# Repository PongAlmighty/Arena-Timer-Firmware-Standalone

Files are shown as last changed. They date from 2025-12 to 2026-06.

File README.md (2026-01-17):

# Arena Timer Firmware

A professional countdown timer system for competitive arenas, combat sports, and event timing. Built on the Waveshare RP2040-Zero with a vibrant 64x32 RGB LED matrix display, web-based control, and seamless integration with [FightTimer](https://github.com/PongAlmighty/FightTimer) by PongAlmighty.

## Features

### Display & Visual Customization
- **64x32 RGB LED Matrix** with full color control
- **Dynamic Color Thresholds** - automatically change colors as time decreases
- **Multiple Font Choices** - Sans, Serif, Monospace, Retro/Pixel styles
- **Adjustable Brightness** - 0-255 levels for any lighting condition
- **Character Spacing Control** - fine-tune text appearance
- **Display Rotation** - flip orientation 180° with one button

### Timer Controls
- **Countdown Mode** - configurable duration up to 60 minutes
- **Start/Pause/Reset** - full manual control
- **Sub-Second Precision** - displays tenths of seconds under 1 minute
- **Visual States** - blinking when paused, flashing when expired

### Web Interface
- **Responsive Three-Column Layout** - Timer controls, color settings, system status
- **Real-Time Console** - live event logging with timestamps
- **Live Updates** - automatic status refresh and button state management
- **Mobile Friendly** - works on phones, tablets, and desktops

### Network & Integration
- **DHCP Support** with static IP fallback (10.0.0.21)
- **mDNS Hostname** - access via `http://arenatimer.local`
- **FightTimer Integration** - Socket.IO connection for synchronized timing (credit: [PongAlmighty](https://github.com/PongAlmighty/))
- **RESTful API** - control timer programmatically

## Hardware

### Required Components
- **Silicognition RP2040-Shim** microcontroller
  - Designed to solder directly to the HUB75 input header on the back of the matrix
  - Provides integrated power regulation (5V to 3.3V)
- **64x32 RGB LED Matrix Panel** (HUB75 interface, P5 pitch recommended)
- **W5500 Ethernet Module** (SPI interface, PoE-FeatherWing or compatible)
- **5V Power Supply** (minimum 2A, 4A recommended for full brightness / more pixels)
  - I used a 5V 20W PoE splitter mounted to the back of the enclosure

### Pin Configuration

**Important:** This firmware uses a specific pin mapping optimized for the RP2040-Shim mounting directly to the HUB75 header. The Ethernet module uses SPI1 to avoid conflicts with the Matrix control signals.

#### RP2040-Shim GPIO Pinout

| RP2040 GPIO | Function | Peripheral | Shim Label | Notes |
|---|---|---|---|---|
| **GPIO 0** | Output Enable (OE) | Matrix | TX | Active low |
| **GPIO 1** | Latch (LAT) | Matrix | RX | |
| **GPIO 6** | Red Data 2 (R2) | Matrix | D4 | Bottom half |
| **GPIO 10** | SPI Clock | Ethernet | SCK | SPI1 |
| **GPIO 11** | SPI MOSI | Ethernet | MOSI | SPI1 |
| **GPIO 12** | SPI MISO | Ethernet | MISO | SPI1 |
| **GPIO 16** | Red Data 1 (R1) | Matrix | SDA | Top half |
| **GPIO 17** | Green Data 1 (G1) | Matrix | SCL | Top half |
| **GPIO 19** | Green Data 2 (G2) | Matrix | D6 | Bottom half |
| **GPIO 20** | Blue Data 1 (B1) | Matrix | D9 | Top half |
| **GPIO 21** | SPI Chip Select | Ethernet | D11 | CS for W5500 |
| **GPIO 22** | Matrix Clock (CLK) | Matrix | D13 | Pixel clock |
| **GPIO 25** | Blue Data 2 (B2) | Matrix | D25 | Bottom half |
| **GPIO 26** | Address D | Matrix | A3 | Row select |
| **GPIO 27** | Address C | Matrix | A2 | Row select |
| **GPIO 28** | Address B | Matrix | A1 | Row select |
| **GPIO 29** | Address A | Matrix | A0 | Row select |

> **Warning:** GPIO 24 is hardwired to VBUS sensing. Never use for I/O or the board will crash.

#### HUB75 Connector Pinout (Matrix Side)

| HUB75 Pin | Signal | RP2040 GPIO | Function |
|---|---|---|---|
| 1 | R1 | GPIO 16 | Red Data (Top) |
| 2 | G1 | GPIO 17 | Green Data (Top) |
| 3 | B1 | GPIO 20 | Blue Data (Top) |
| 4 | GND | - | Ground |
| 5 | R2 | GPIO 6 | Red Data (Bottom) |
| 6 | G2 | GPIO 19 | Green Data (Bottom) |
| 7 | B2 | GPIO 25 | Blue Data (Bottom) |
| 8 | GND | - | Ground |
| 9 | A | GPIO 29 | Address A |
| 10 | B | GPIO 28 | Address B |
| 11 | C | GPIO 27 | Address C |
| 12 | D | GPIO 26 | Address D |
| 13 | CLK | GPIO 22 | Pixel Clock |
| 14 | LAT | GPIO 1 | Latch |
| 15 | OE | GPIO 0 | Output Enable |
| 16 | GND | - | Ground |

> **Note:** The RP2040-Shim is powered by connecting 5V from the matrix power supply to the VUSB pin (3rd pin on right header). The onboard regulator converts this to 3.3V for logic. Do not connect USB while external 5V is applied unless using a data-only cable.

For complete wiring diagrams and PCB design files, see [wiring_connections.md](wiring_connections.md).

### Custom PCB & 3D Enclosure

**Custom PCB** is currently in production and will be added to this repository once tested and verified.

**3D Enclosure** files for a custom LED matrix enclosure are available in the `3d-models/` directory:
- `Timer Assembly v23.step` - STEP format for CAD editing
- `Timer Assembly v23.f3z` - Fusion 360 archive format

Files are print-ready and designed for:
- Standard 64x32 P5 RGB matrix panels
- RP2040-Shim direct mounting to HUB75 header
- PoE splitter bracket mount

## Quick Start

### 1. Flash Firmware
```bash
pio run --target upload
```

### 2. Network Connection
The timer will attempt DHCP, then fall back to `10.0.0.21` if unavailable. The assigned IP displays on the matrix for 5 seconds at startup.

### 3. Web Interface
Access the control panel at:
- `http://arenatimer.local` (mDNS)
- `http://[IP_ADDRESS]` (direct)

Use the web interface to:
- Start, pause, and reset the timer
- Set duration (minutes and seconds)
- Configure color thresholds for time-based alerts
- Adjust display settings (font, brightness, letter spacing)
- Flip display orientation
- Monitor system status and event logs

### 4. FightTimer Integration
To connect with FightTimer:
1. Ensure FightTimer is running on your network
2. In the **WebSocket Connection** section, enter:
   - **Host**: IP address of the computer running FightTimer
   - **Port**: `8765` (default Socket.IO port)
   - **Path**: `/socket.io/`
3. Click **Connect**

The timer will automatically sync with FightTimer's start/stop/reset commands and duration settings.

**What Gets Synchronized:**
- ✅ Timer start/stop/reset commands
- ✅ Duration changes
- ✅ Time remaining updates
- ✅ Expired/paused states

FightTimer sends `timer_update` events via Socket.IO that control the Arena Timer display.

**Alternative connection methods:**

Via code in `src/main.cpp`:
```cpp
void setup() {
    // ... existing setup code ...
    wsClient->connect("192.168.1.100", 8765, "/socket.io/");
}
```

Via API endpoint:
```bash
curl -X POST "http://arenatimer.local/api/websocket/connect" \
  -d "host=192.168.1.100&port=8765&path=/socket.io/"
```

## Configuration

### Network Settings
Edit `src/main.cpp` to change network defaults:
```cpp
uint8_t mac[] = {0xDE, 0xAD, 0xBE, 0xEF, 0xFE, 0xED};  // MAC address
uint8_t static_ip[] = {10, 0, 0, 21};                   // Static IP fallback
const char* hostname = "arenatimer";                     // mDNS hostname
```

### Display Settings
Configure default display settings in `src/main.cpp`:
```cpp
// Set default font
timerDisplay.setFont(&FreeSansBold12pt7b);

// Set default duration (hours, minutes, seconds)
timerDisplay.getTimer().setDuration({0, 3, 0});  // 3 minutes

// Color thresholds (set via web interface or programmatically)
timerDisplay.addColorThreshold(120, 255, 255, 0);  // Yellow at 2 minutes
timerDisplay.addColorThreshold(60, 255, 0, 0);     // Red at 1 minute
```

### Available Fonts
- **Sans**: `FreeSans9pt7b`, `FreeSans12pt7b`, `FreeSansBold9pt7b`, `FreeSansBold12pt7b`
- **Serif**: `FreeSerif9pt7b`, `FreeSerif12pt7b`, `FreeSerifBold9pt7b`, `FreeSerifBold12pt7b`
- **Mono**: `FreeMono9pt7b`, `FreeMono12pt7b`, `FreeMonoBold9pt7b`, `FreeMonoBold12pt7b`
- **Retro**: `Org_01`, `Picopixel`, `TomThumb` (ultra-compact pixel fonts)
- **Custom**: `Aquire_BW0ox12pt7b`, `AquireBold_8Ma6012pt7b`, `AquireLight_YzE0o12pt7b`

### Pin Configuration
Default pins are defined in `include/RGBMatrix.h` for the Waveshare RP2040-Zero. Modify if using different pin connections.

### Performance Optimization
The firmware includes debug flags that can be disabled for optimal timing performance:

```cpp
// src/main.cpp
#define DEBUG_MAIN false

// src/WebServer.cpp
#define DEBUG_WEBSERVER false

// src/WebSocketClient.cpp
#define DEBUG_WEBSOCKET false
```

When all debug flags are `false`, Serial output is disabled, eliminating timing delays. This is recommended for production use.

## API Reference

The timer exposes a RESTful API for programmatic control:

### Timer Control
```bash
# Start timer
POST /api?action=start

# Pause timer
POST /api?action=pause

# Reset timer
POST /api?action=reset

# Flip display orientation
POST /api?action=flip
```

### Settings
```bash
# Update timer settings
POST /api?action=settings&duration=180&font=4&spacing=3&brightness=255

# Update color thresholds
POST /api/thresholds
Content-Type: application/x-www-form-urlencoded
thresholds=120:%23FFFF00|60:%23FF0000&default=%2300FF00
```

### Status Information
```bash
# Get timer status
GET /api/status

# Get network information
GET /api/network/status

# Get WebSocket connection status
GET /api/websocket/status
```

### WebSocket Connection
```bash
# Connect to FightTimer
POST /api/websocket/connect
Content-Type: application/x-www-form-urlencoded
host=192.168.1.100&port=8765&path=/socket.io/

# Disconnect
POST /api/websocket/disconnect
```

## Troubleshooting

### Display Issues
- **Blank display**: Check power supply (5V, minimum 2A recommended)
- **Corrupted display**: Verify HUB75 cable connections
- **Wrong colors**: Check RGB pin mappings in `src/RGBMatrix.cpp`

### Network Issues
- **Can't access web interface**: Check Ethernet cable, verify IP on display at startup
- **DHCP not working**: Timer falls back to static IP `10.0.0.21`
- **mDNS not resolving**: Try direct IP address instead

### FightTimer Connection
- **Won't connect**: Verify FightTimer is running and accessible at the specified host/port
- **Connects but no updates**: Check that FightTimer is sending `timer_update` Socket.IO events
- **Frequent disconnects**: Check network stability between devices

## Development

### Build Environment
- **Framework**: Arduino
- **Platform**: Raspberry Pi Pico (RP2040)
- **Tool**: PlatformIO

### Key Libraries
- **Adafruit Protomatter** - RGB matrix driver
- **Ethernet** - W5500 network interface
- **WebSockets** - Socket.IO client (links2004/arduinoWebSockets)
- **EthernetBonjour** - mDNS support

### Building from Source
```bash
# Clone repository
git clone https://github.com/EVAC-AZ/Arena-Timer-Firmware.git
cd Arena-Timer-Firmware

# Install dependencies
pio pkg install

# Build and upload
pio run --target upload

# Monitor serial output (optional)
pio device monitor
```

### Project Structure
```
arena-timer-firmware/
├── src/
│   ├── main.cpp              # Entry point and configuration
│   ├── Timer.cpp             # Core timer logic
│   ├── TimerDisplay.cpp      # LED matrix display control
│   ├── RGBMatrix.cpp         # Low-level matrix driver
│   ├── WebServer.cpp         # Web server and API
│   └── WebSocketClient.cpp   # Socket.IO client
├── include/
│   ├── Timer.h
│   ├── TimerDisplay.h
│   ├── RGBMatrix.h
│   ├── WebServer.h
│   ├── WebSocketClient.h
│   └── CustomFonts/          # Custom font definitions
├── 3d-models/                # Enclosure models
├── docs/                     # Documentation
├── platformio.ini            # Build configuration
└── README.md
```

### Future Plans
A standalone Arduino/PlatformIO library is planned to simplify integration of this timer system into other projects. The goal is to separate the timing/web UI/FightTimer integration code from the hardware-specific code, allowing use with different display hardware and microcontrollers (ESP32, ESP8266, etc.).

## Credits

- **FightTimer Integration**: [PongAlmighty/FightTimer](https://github.com/PongAlmighty/FightTimer) - Synchronized timing system for combat sports
- **RGB Matrix Control**: Adafruit Protomatter library
- **WebSocket Library**: Arduino WebSockets by links2004
- **Enclosure Design**: EVAC-AZ

## License

This project is open source. See `LICENSE` for details.

## Contributing

Contributions are welcome! Please:
1. Fork the repository
2. Create a feature branch
3. Make your changes with clear commits
4. Submit a pull request

For bug reports and feature requests, open an issue on GitHub.

---

**Built for arena timing excellence** 🏆

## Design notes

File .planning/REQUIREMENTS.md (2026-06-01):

# Requirements — Arena Timer Local Control & Sync

## v1 Requirements

### Button Hardware

- [x] **BTN-01**: GPIO14 and GPIO15 initialized as `INPUT_PULLUP` (active-low) in `setup()` — eliminates floating-pin phantom presses at boot
- [x] **BTN-02**: Button states polled via Bounce2 library; poll is the first call in `loop()` to prevent starvation during HTTP blocking
- [x] **BTN-03**: `thomasfredericks/Bounce2@^2.71` added to `platformio.ini` `lib_deps`; debounce interval set to 25ms

### Button UX

- [x] **BTN-04**: Button 1 (GPIO14) solo press toggles between running and stopped only: RESET → RUNNING on first press; RUNNING → STOPPED on press; STOPPED → RUNNING on press. Button 1 alone NEVER resets the timer — reset is only possible via the chord (BTN-06).
- [x] **BTN-05**: Button 2 (GPIO15) held for ≥400ms enters "armed" state; releasing Button 2 at any point disarms with no further action taken
- [x] **BTN-06**: Button 1 pressed while system is in armed state → stop & reset (timer returns to RESET state regardless of whether it was RUNNING or STOPPED)
- [x] **BTN-07**: While armed, display overrides to yellow "STOP?" text blinking at 1 Hz; display returns to normal timer on disarm or confirm

### FightTimer Integration

- [x] **SYNC-01**: Every button action (start, stop, reset) emits a `timer_control` Socket.IO event to FightTimer with the corresponding action string before (not after) local timer state change
- [x] **SYNC-02**: `handleTimerUpdate()` suppresses incoming `timer_update` for 500ms after any local button emit, matched by action type; suppression is one-shot (consumed on first match)
- [x] **SYNC-03**: On receiving `timer_update {action: start}`, Arena Timer sets its timer to FightTimer's actual remaining time — if `time_left` is present in the event payload use it directly; otherwise emit `request_timer_status` and apply the response

## v2 Requirements (Deferred)

- Long-press Button 1 to cycle through fight duration presets (e.g., 2 min / 3 min / 5 min) — useful if FightTimer is unavailable
- Display of current timer duration on boot/reset for operator confirmation
- Configurable debounce threshold via web UI (for different button hardware on future PCB revisions)

## Out of Scope

- Pause as a distinct state — FightTimer has no pause action; stop-without-reset is the equivalent; the firmware stop/resume behavior maps to FightTimer start/stop
- Button interrupt mode — RP2040 hardware interrupts during WebSocket DMA transfers introduce race conditions with no debugging path; polling is correct for this architecture
- Authentication/authorization on button actions — device is on an isolated arena LAN; unauthenticated control is consistent with the existing web API
- Display orientation flip implementation — separate concern tracked in CONCERNS.md; not related to button control

## Traceability

| REQ-ID | Phase | Status |
|---|---|---|
| BTN-01 | Phase 1 | Complete |
| BTN-02 | Phase 1 | Complete |
| BTN-03 | Phase 1 | Complete |
| BTN-04 | Phase 2 | Complete |
| BTN-05 | Phase 2 | Complete |
| BTN-06 | Phase 2 | Complete |
| BTN-07 | Phase 2 | Complete |
| SYNC-01 | Phase 3 | Complete |
| SYNC-02 | Phase 3 | Complete |
| SYNC-03 | Phase 3 | Complete |

---
*Requirements defined: 2026-05-30*
*Traceability updated: 2026-05-31*

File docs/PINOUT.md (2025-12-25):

# Hardware Pinout (VERIFIED WORKING)

**Device**: Arena Timer  
**Controller**: Silicognition RP2040-Shim  
**Network**: POE-FeatherWing (W5500)  
**Display**: HUB75 RGB LED Matrix (64x32)

## Matrix Pin Mapping
| Signal | GPIO | Board Label |
|---|---|---|
| R1 | 16 | SDA |
| G1 | 17 | SCL |
| B1 | 20 | D9 |
| R2 | 6  | D4 |
| G2 | 19 | D6 |
| B2 | 25 | D25 |
| CLK | 22 | D13 |
| **LAT** | **1** | **RX** |
| **OE** | **0** | **TX** |
| A | 29 | A0 |
| B | 28 | A1 |
| C | 27 | A2 |
| D | 26 | A3 |

> **Note**: LAT and OE use GPIO 0/1 (TX/RX pins). USB Serial still works.

## Ethernet (SPI1)
| Signal | GPIO | Board Label |
|---|---|---|
| SCK | 10 | SCK |
| MOSI | 11 | MOSI |
| MISO | 12 | MISO |
| CS | 21 | D10 |

## ⚠️ Reserved Pins
- **GPIO 21**: Ethernet CS - do not use for matrix
- **GPIO 24**: VBUS sensing - never use as output (will crash!)
- **GPIO 23**: Internal Neopixel

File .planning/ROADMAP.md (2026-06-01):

# Roadmap: Arena Timer Firmware — Local Control & Sync

## Overview

Three horizontal layers build the complete button-control and sync capability. Phase 1 establishes the hardware foundation — stable GPIO init and a debounced ButtonHandler class. Phase 2 adds the full button UX on top of that stable base — start/stop toggle, chord-armed state, and the "STOP?" matrix overlay. Phase 3 closes the loop with FightTimer — outbound emit, echo suppression, and the startup sync fix that eliminates the ~1s display offset.

## Phases

**Phase Numbering:**

- Integer phases (1, 2, 3): Planned milestone work
- Decimal phases (2.1, 2.2): Urgent insertions (marked with INSERTED)

Decimal phases appear between their surrounding integers in numeric order.

- [x] **Phase 1: ButtonHandler Foundation** - GPIO init, Bounce2 integration, ButtonHandler class scaffold (completed 2026-05-31)
- [x] **Phase 2: Button UX** - Start/stop toggle, chord gesture, armed display overlay (completed 2026-05-31)
- [x] **Phase 3: Socket.IO Integration** - emitTimerControl(), echo suppression, timer sync fix

## Phase Details

### Phase 1: ButtonHandler Foundation

**Goal**: A stable, debounced button hardware layer exists and can be extended with behavior
**Depends on**: Nothing (first phase)
**Requirements**: BTN-01, BTN-02, BTN-03
**Success Criteria** (what must be TRUE):

  1. GPIO14 and GPIO15 are initialized as INPUT_PULLUP — pressing either button while monitoring serial shows a clean LOW transition with no phantom events at boot
  2. Bounce2 polls both buttons as the first call in loop(); a rapid sequence of button presses produces exactly one falling-edge event per physical press (no chatter)
  3. Bounce2 library is declared in platformio.ini lib_deps and the project builds without error

**Plans**: 2 plans
Plans:
**Wave 1**

- [x] 01-01-PLAN.md — Bounce2 lib_deps + ButtonHandler class scaffold (header + implementation)

**Wave 2** *(blocked on Wave 1 completion)*

- [x] 01-02-PLAN.md — Wire ButtonHandler into main.cpp + pio run build verification

### Phase 2: Button UX

**Goal**: A box ref can start, stop, and arm-then-reset the timer using the two physical buttons
**Depends on**: Phase 1
**Requirements**: BTN-04, BTN-05, BTN-06, BTN-07
**Success Criteria** (what must be TRUE):

  1. Pressing Button 1 alone toggles between running and stopped only: first press starts a RESET timer (→ RUNNING), second press stops the clock without resetting it (→ STOPPED), third press resumes (→ RUNNING). Button 1 alone never causes a reset under any circumstance — RESET state is only reachable via the chord (BTN-06)
  2. Holding Button 2 for ≥400ms shows yellow blinking "STOP?" on the matrix; releasing Button 2 without pressing Button 1 returns the display to normal with no timer state change
  3. While Button 2 is held (armed), pressing Button 1 stops and resets the timer regardless of whether it was running or stopped — matrix returns to RESET display

**Plans**: 2 plans
Plans:
**Wave 1**

- [x] 02-01-PLAN.md — ButtonHandler state machine (armed/disarmed, one-shot events) + WebSocketClient emitTimerControl stub

**Wave 2** *(blocked on Wave 1 completion)*

- [x] 02-02-PLAN.md — TimerDisplay armed overlay (yellow STOP? blink) + main.cpp button event routing

### Phase 3: Socket.IO Integration

**Goal**: All button actions sync to FightTimer bidirectionally with no echo loops and no startup time offset
**Depends on**: Phase 2
**Requirements**: SYNC-01, SYNC-02, SYNC-03
**Success Criteria** (what must be TRUE):

  1. Pressing any button emits a timer_control Socket.IO event (action: start / stop / reset) to FightTimer before the local timer state changes — FightTimer's log shows the event arriving within one LAN RTT
  2. After a local button emit, the echoed timer_update from FightTimer does not re-trigger the local timer; the suppression window is consumed on first match and does not block a subsequent legitimate remote action
  3. When FightTimer sends timer_update {action: start}, the Arena Timer's displayed countdown matches FightTimer's actual remaining time within one LAN RTT — the ~1s startup offset is eliminated

**Plans**: 1 plan
Plans:
**Wave 1**

- [x] 03-01-PLAN.md — WebSocketClient.h private members + WebSocketClient.cpp SYNC-01/02/03 implementation

## Progress

**Execution Order:**
Phases execute in numeric order: 1 → 2 → 3

| Phase | Plans Complete | Status | Completed |
|---|---|---|---|
| 1. ButtonHandler Foundation | 2/2 | Complete | 2026-05-31 |
| 2. Button UX | 2/2 | Complete | 2026-05-31 |
| 3. Socket.IO Integration | 1/1 | Complete | 2026-05-31 |

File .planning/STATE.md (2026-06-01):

---
gsd_state_version: 1.0
milestone: v1.0
milestone_name: milestone
status: complete
last_updated: "2026-05-31T00:00:00Z"
last_activity: 2026-05-31 -- All phases UAT complete; namespace emit fix, font restore fix, sync round-trip removed
progress:
  total_phases: 3
  completed_phases: 3
  total_plans: 5
  completed_plans: 5
  percent: 100
---

# Project State

## Project Reference

See: .planning/PROJECT.md (updated 2026-05-30)

**Core value:** A box ref can start, stop, and reset their fight clock with physical buttons, and those actions are immediately reflected in FightTimer — so cutting to that fight on screen always shows the correct, live time.
**Current focus:** All 3 phases complete — milestone v1.0 UAT done

## Current Position

All 3 phases complete. UAT done.

- Phase 01 (buttonhandler-foundation) — COMPLETE, UAT done
- Phase 02 (button-ux) — COMPLETE, UAT done
- Phase 03 (socket-io-integration) — COMPLETE, UAT done

Progress: [##########] 100%

## Performance Metrics

**Velocity:**

- Total plans completed: 5
- Average duration: —
- Total execution time: —

**By Phase:**

| Phase | Plans | Total | Avg/Plan |
|---|---|---|---|
| 01 | 2 | - | - |
| 02 | 2 | - | - |
| 03 | 1 | - | - |

**Recent Trend:**

- Last 5 plans: —
- Trend: —

*Updated after each plan completion*

## Accumulated Context

### Decisions

Decisions are logged in PROJECT.md Key Decisions table.
Recent decisions affecting current work:

- Architecture: ButtonHandler never calls _timer directly — all actions go through wsClient->emitTimerControl(), timer state changes flow through handleTimerUpdate() exclusively
- UX: Chord gesture (Button 2 held ≥400ms, then Button 1) for stop-reset — prevents accidental destructive action
- Echo suppression: 500ms per-action window, one-shot consumption — prevents FightTimer echo loop without blocking legitimate remote events
- request_timer_status payload must include {timer_id:1} — empty payload causes FightTimer to return timers_status (plural event) not timer_status; hardcoded 1 is correct for single-mode arena setup
- SYNC-03 setDuration->reset->start order is load-bearing per Timer.h API; do not reorder
- _initialSyncPending cleared on disconnect to prevent stale sync flag surviving reconnects
- Removed request_timer_status round-trip on runtime start — FightTimer truncates time_left so round-trip caused 1s offset; both timers start from configured duration and stay in sync

### Pending Todos

None.

### Blockers/Concerns

None.

## Deferred Items

| Category | Item | Status | Deferred At |
|---|---|---|---|
| v2 | Long-press Button 1 to cycle fight duration presets | Deferred | Requirements |
| v2 | Display current duration on boot/reset | Deferred | Requirements |
| v2 | Configurable debounce threshold via web UI | Deferred | Requirements |

## Session Continuity

Last session: 2026-05-31T00:00:00Z
Stopped at: All 3 phases UAT complete — milestone v1.0 done
Resume file: None — milestone complete

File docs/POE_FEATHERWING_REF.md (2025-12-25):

# PoE-FeatherWing Reference Guide

Source: [Silicognition PoE-FeatherWing Product Page](https://silicognition.com/Products/poe-featherwing/)

## Overview
The PoE-FeatherWing is a drop-in replacement for the Adafruit Ethernet FeatherWing, adding Power over Ethernet (PoE) capability. It uses the **WIZnet W5500** Ethernet controller.

## Key Features
- **PoE (Isolated)**: IEEE 802.3at Class 1, Mode A and Mode B.
- **Output Power**: Up to 4 W available for the Feather and peripherals.
- **Unique MAC Address**: Built-in Microchip 24AA02E48 provides a globally unique MAC address via I2C.
- **Compatibility**: 
  - Standard Arduino Ethernet driver.
  - MicroPython/CircuitPython WIZNET5K driver.
  - Drop-in replacement for Adafruit Ethernet FeatherWing.

## Hardware Details & Jumpers
- **Solder Jumpers**:
  - **IRQ**: Allows connecting the W5500 IRQ signal to a Feather pin (default is disconnected).
  - **I2C Addr**: Configure the address of the MAC address chip (24AA02E48). Default I2C address is **0x50**.
- **Solder Pads**:
  - Available for additional ground or power signaling on the bottom of the board.

## Software Integration (Arduino)
The board works with the standard `Ethernet` library, but for RP2040-Shim specifically, initialization requires directing the library to the correct SPI bus and CS pin.

### Reading the Unique MAC address (I2C)
The MAC address is stored in the 24AA02E48 chip at I2C address **0x50**. 
Registers for MAC: `0xFA` through `0xFF`.

```cpp
#include <Wire.h>
byte mac[6];
void readMac() {
  Wire.beginTransmission(0x50);
  Wire.write(0xFA);
  Wire.endTransmission();
  Wire.requestFrom(0x50, 6);
  for (int i=0; i<6; i++) mac[i] = Wire.read();
}
```

## Physical Footprint
- Identical to Adafruit Feather footprint.
- Optimized for clearance around the RJ45 jack when used with the RP2040-Shim.

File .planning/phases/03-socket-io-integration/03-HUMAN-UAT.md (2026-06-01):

---
status: complete
phase: 03-socket-io-integration
source: [03-VERIFICATION.md]
started: 2026-05-31T22:30:00Z
updated: 2026-05-31T22:30:00Z
---

## Current Test

[awaiting human testing]

## Tests

### 1. Emit-before-local ordering on serial
expected: Serial log shows `emitTimerControl: sent 42["timer_control",{"action":"start"}]` BEFORE any local timer start log when Button 1 is pressed while connected to FightTimer
result: pass

### 2. Echo suppression — 500ms window
expected: Immediately after a button press, a FightTimer echo of the same action within 500ms logs `Echo suppressed: start` and does NOT re-trigger the timer. A second echo >500ms later applies normally.
result: pass — `Echo suppressed: start/stop/reset` confirmed. Note: chord double-emit (stop+reset) overwrites suppression slot so stop echo slips through, but stop-on-stopped is a no-op; end state is correct.

### 3. Runtime start sync — time_left applied to display
expected: Serial shows `Runtime start: emitted request_timer_status` then `SYNC-03 applied: time_left=N`; display updates to the corrected remaining time, not the full preset duration
result: pass — round-trip sync removed; both timers start from configured duration simultaneously. FightTimer's time_left truncation caused 1s offset; fix was to remove the round-trip rather than compensate.

### 4. Initial connect sync — no request_timer_status round-trip
expected: On power-cycle with FightTimer running, serial shows `is_initial_sync: next start skips request_timer_status`; no `request_timer_status` is emitted for the connect-sync start event
result: pass — rebooted arena timer while FightTimer was running; arena timer started in sync with FightTimer on reconnect with no extra round-trip.

### 5. Offline fallback — no crash
expected: With no FightTimer connection, pressing Button 1 repeatedly applies local timer normally with no crash, hang, or watchdog reset over 60s
result: pass — no crash. Found display bug: font/size not restored after armed overlay, causing small default font on reset. Fixed by applying `_matrix.setFont(_current_font)` + `_matrix.setTextSize(_text_size)` at top of `draw()`.

## Summary

total: 5
passed: 5
issues: 1
pending: 0
skipped: 0
blocked: 0

## Gaps

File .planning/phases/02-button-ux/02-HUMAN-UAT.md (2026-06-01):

---
status: complete
phase: 02-button-ux
source: [02-VERIFICATION.md]
started: 2026-05-31T00:00:00Z
updated: 2026-05-31T00:00:00Z
---

## Current Test

All tests passed.

## Tests

### 1. Armed display overlay
expected: Hold Button 2 >= 400ms → matrix displays yellow "STOP?" blinking at 1Hz. Release Button 2 → matrix returns to normal timer display with no state change (timer not stopped/reset).
result: pass

### 2. Chord reset
expected: Hold Button 2 + press Button 1 while armed → timer stops and resets, from both RUNNING and STOPPED states.
result: pass

### 3. Solo Button 1 toggle / no-reset guarantee
expected: Repeated Button 1 presses alone cycle RESET→RUNNING→STOPPED→RUNNING with no accidental resets. Button 1 never causes a reset when pressed without Button 2 held.
result: pass

## Summary

total: 3
passed: 3
issues: 0
pending: 0
skipped: 0
blocked: 0

## Gaps

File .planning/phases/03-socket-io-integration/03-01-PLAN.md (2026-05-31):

---
phase: 03-socket-io-integration
plan: 01
type: execute
wave: 1
depends_on: []
files_modified:
  - include/WebSocketClient.h
  - src/WebSocketClient.cpp
autonomous: true
requirements:
  - SYNC-01
  - SYNC-02
  - SYNC-03

must_haves:
  truths:
    - "Pressing Button 1 or the chord emits a Socket.IO timer_control event to FightTimer before the local timer state changes"
    - "A second button press within 500ms of FightTimer echoing back the same action is silently discarded — the timer does not double-trigger"
    - "When FightTimer broadcasts timer_update {action: start} for a runtime start, the Arena Timer immediately starts then adjusts its countdown to FightTimer's actual remaining time within one LAN RTT"
    - "When FightTimer broadcasts the initial connect sync (reset with is_initial_sync: true then start), the Arena Timer applies the synced duration without an extra request_timer_status round-trip"
    - "When FightTimer sends no timer_control events (offline), button actions still apply locally with no crash or hang"
  artifacts:
    - path: "include/WebSocketClient.h"
      provides: "Echo suppression + sync flag private members"
      contains: "_suppressAction"
    - path: "include/WebSocketClient.h"
      provides: "Constructor initializer for new members"
      contains: "_suppressAction(\"\"), _suppressUntilMs(0), _initialSyncPending(false)"
    - path: "src/WebSocketClient.cpp"
      provides: "emit-first timer_control with suppression window set"
      contains: "42[\"timer_control\""
    - path: "src/WebSocketClient.cpp"
      provides: "Echo suppression check at top of handleTimerUpdate()"
      contains: "_suppressAction.length() > 0"
    - path: "src/WebSocketClient.cpp"
      provides: "Runtime start triggers request_timer_status with timer_id:1"
      contains: "request_timer_status\",{\"timer_id\":1}"
    - path: "src/WebSocketClient.cpp"
      provides: "timer_status event branch in handleWebSocketEvent()"
      contains: "arr[0] == \"timer_status\""
    - path: "src/WebSocketClient.cpp"
      provides: "is_initial_sync detection in reset branch"
      contains: "is_initial_sync"
    - path: "src/WebSocketClient.cpp"
      provides: "Heartbeat guard in start branch"
      contains: "is_heartbeat"
    - path: "src/WebSocketClient.cpp"
      provides: "_initialSyncPending cleared on WStype_DISCONNECTED"
      contains: "_initialSyncPending = false"
  key_links:
    - from: "src/WebSocketClient.cpp emitTimerControl()"
      to: "FightTimer handle_timer_control"
      via: "_client.sendTXT with 42[\"timer_control\",{\"action\":\"...\"}]"
      pattern: "sendTXT.*42.*timer_control"
    - from: "src/WebSocketClient.cpp handleTimerUpdate() start branch"
      to: "FightTimer handle_timer_status_request"
      via: "_client.sendTXT(\"42[\\\"request_timer_status\\\",{\\\"timer_id\\\":1}]\")"
      pattern: "sendTXT.*request_timer_status.*timer_id"
    - from: "src/WebSocketClient.cpp handleWebSocketEvent() timer_status branch"
      to: "_timer->setDuration + reset + start"
      via: "time_left parsed from arr[1]"
      pattern: "arr\\[0\\] == \"timer_status\""
---

<objective>
Upgrade WebSocketClient from Phase 2's local-only stub to a fully bidirectional Socket.IO integration with echo suppression and timer sync correction.

Three surgical changes land all three SYNC requirements:
1. SYNC-01 (D-01/D-02/D-03): emitTimerControl() emits 42["timer_control",...] before calling the local timer method; skips emit when offline so buttons still work standalone.
2. SYNC-02 (D-04/D-05/D-06): After each emit, store (_suppressAction, _suppressUntilMs). At the top of handleTimerUpdate(), consume and discard the echo on first match within 500ms.
3. SYNC-03 (D-07 through D-12): On runtime start, immediately start the local timer then send request_timer_status (with timer_id:1 — critical). On receiving timer_status, apply setDuration+reset+start from time_left. Skip the round-trip on initial connect sync (tracked by _initialSyncPending). Guard heartbeat start events from triggering a 5-second polling flood.

Purpose: Closes the last loop — box ref button presses propagate to FightTimer, FightTimer echoes don't cause double-triggers, and the ~1s startup offset from starting at full duration is eliminated.

Output: Two modified files. No new files, no new libraries, no main.cpp changes.
</objective>

<execution_context>
@/Users/themightypong/.claude/get-shit-done/workflows/execute-plan.md
@/Users/themightypong/.claude/get-shit-done/templates/summary.md
</execution_context>

<context>
@.planning/PROJECT.md
@.planning/ROADMAP.md
@.planning/STATE.md
@.planning/phases/03-socket-io-integration/03-CONTEXT.md
@.planning/phases/03-socket-io-integration/03-RESEARCH.md
@.planning/phases/03-socket-io-integration/03-PATTERNS.md
</context>

<tasks>

<task type="auto" tdd="false">
  <name>Task 1: Add private members to WebSocketClient.h (D-04, D-12)</name>
  <files>include/WebSocketClient.h</files>
  <read_first>
    - include/WebSocketClient.h — read the full file to see the current private member block (lines 40–48) and constructor declaration; insertion points are after _autoReconnect and in the constructor initializer list
  </read_first>
  <action>
    In the private section of WebSocketClient.h, append three new members after the _autoReconnect line. The block already has bool, unsigned long, and unsigned int members — follow the same type/name/comment convention. Add a grouping comment "// Phase 3: Socket.IO bidirectional sync state" before the three new declarations.

    The three members to add (per D-04 and D-12):
    - String _suppressAction — the action string being echo-suppressed; initialized to "" meaning not suppressing
    - unsigned long _suppressUntilMs — millis() expiry of the 500ms suppression window (SYNC-02)
    - bool _initialSyncPending — when true, the next start event is the tail of an initial connect sync and skips the request_timer_status round-trip (SYNC-03)

    These declarations go in the private section between _autoReconnect (line 47) and the "// Socket.IO support" comment block. Do not insert them inside any #ifdef block.

    Note: The constructor initializer list lives in WebSocketClient.cpp (lines 18–22), not in the header. Do NOT add initialization here — that is handled in Task 2.
  </action>
  <verify>
    <automated>grep -c "_suppressAction" /Users/themightypong/Documents/PythonCode/Arena-Timer-Firmware-Standalone/include/WebSocketClient.h</automated>
  </verify>
  <acceptance_criteria>
    - include/WebSocketClient.h contains the line: String _suppressAction;
    - include/WebSocketClient.h contains the line: unsigned long _suppressUntilMs;
    - include/WebSocketClient.h contains the line: bool _initialSyncPending;
    - All three members are inside the private: section, not inside any #ifdef block
    - The file still compiles: pio run exits 0 (verified in Task 2's build step)
  </acceptance_criteria>
  <done>Three private members declared; header reflects the complete Phase 3 WebSocketClient state requirements</done>
</task>

<task type="auto" tdd="false">
  <name>Task 2: Implement SYNC-01 + SYNC-02 + SYNC-03 in WebSocketClient.cpp</name>
  <files>src/WebSocketClient.cpp</files>
  <read_first>
    - src/WebSocketClient.cpp — read lines 18–22 (constructor initializer list), lines 283–304 (WStype_DISCONNECTED handler), lines 317–393 (WStype_TEXT / handleWebSocketEvent JSON dispatch), lines 421–488 (handleTimerUpdate() + emitTimerControl() stub)
    - .planning/phases/03-socket-io-integration/03-PATTERNS.md — PATTERNS.md contains the exact before/after code for every insertion point with line numbers; use it as the implementation reference
    - .planning/phases/03-socket-io-integration/03-RESEARCH.md — RESEARCH.md §Critical Finding explains why request_timer_status must include {"timer_id":1} and §Pitfalls lists the 6 pitfalls to avoid
  </read_first>
  <action>
    Make five distinct edits to WebSocketClient.cpp. Apply them in this order to avoid line-number drift from earlier edits:

    EDIT A — Constructor initializer list (lines 18–22): Append _suppressAction(""), _suppressUntilMs(0), _initialSyncPending(false) at the end of the initializer list, before the opening brace. The current list ends with _consecutiveFailures(0). The new list ends with ..., _consecutiveFailures(0), _suppressAction(""), _suppressUntilMs(0), _initialSyncPending(false).

    EDIT B — WStype_DISCONNECTED handler (lines 296–297): After the line "_connectInProgress = false;" add a single new line: _initialSyncPending = false;  — this prevents the sync flag from surviving across reconnects (Pitfall 4 from RESEARCH.md).

    EDIT C — handleWebSocketEvent() WStype_TEXT JSON dispatch (lines 378–392): Inside the if (doc.is<JsonArray>()) block, after the existing timer_update branch (which ends at the closing brace on line 385), add an else if branch for timer_status. The branch checks arr.size() >= 2 && arr[0] == "timer_status" && arr[1].is<JsonObject>(). Inside it: parse int time_left = status["time_left"] | 0; if time_left > 0, compute unsigned int min = (unsigned int)(time_left / 60) and unsigned int sec = (unsigned int)(time_left % 60), then call _timer->setDuration({min, sec, 0}), _timer->reset(), _timer->start() in that exact order (Pitfall 5 — do not reorder). Add DEBUG_PRINT/PRINTLN for "SYNC-03 applied: time_left=" + time_left. The else if must be INSIDE the if (doc.is<JsonArray>()) block, before the closing brace of that block (not after the } else if (doc["timer_update"]...) fallback below). See PATTERNS.md "Modification Area 3" for the exact structure.

    EDIT D — handleTimerUpdate() (lines 421–475): This is the largest edit. Three sub-changes inside this method:

      D1 — Suppression check: After the "if (action == nullptr) { return; }" guard (lines 424–427) and BEFORE the DEBUG_PRINT("Timer action:") line (line 429), insert the SYNC-02 suppression block. Check: _suppressAction.length() > 0 && _suppressAction == action && millis() < _suppressUntilMs. If true: emit DEBUG_PRINT("Echo suppressed: ") + DEBUG_PRINTLN(action), set _suppressAction = "" (one-shot consume, per D-05), then return. The suppression check must precede ALL action dispatch.

      D2 — Start branch replacement (lines 432–437): Replace the entire start branch body with the SYNC-03 runtime-start logic. First, guard heartbeat events: if (obj["is_heartbeat"].as<bool>()) { DEBUG_PRINTLN("Heartbeat start: ignoring"); return; }. Then call _timer->start() (D-08: start immediately). Then branch on _initialSyncPending: if true, set _initialSyncPending = false and log "Initial sync start: skipping request_timer_status"; else send _client.sendTXT("42[\"request_timer_status\",{\"timer_id\":1}]") and log "Runtime start: emitted request_timer_status". The payload {"timer_id":1} is mandatory — {} or null causes FightTimer to return timers_status (plural), which the timer_status branch in handleWebSocketEvent() never matches (RESEARCH.md Critical Finding).

      D3 — Reset branch addition (lines 442–455): After the existing _timer->reset() call, add is_initial_sync detection: if (obj["is_initial_sync"].as<bool>()) { _initialSyncPending = true; DEBUG_PRINTLN("is_initial_sync: next start skips request_timer_status"); }. This sets the flag that D2 above reads. The existing setDuration+reset calls are unchanged.

    EDIT E — emitTimerControl() full replacement (lines 477–488): Replace the entire stub body. New logic: if (_connected) { build String msg = String("42[\"timer_control\",{\"action\":\"") + action + "\"}]"; call _client.sendTXT(msg); log "emitTimerControl: sent " + msg; then set _suppressAction = String(action) and _suppressUntilMs = millis() + 500UL (D-04/D-06 — suppression only when connected). Then unconditionally (outside the if block), dispatch strcmp action to _timer->start() / _timer->stop() / _timer->reset() (D-02 — local timer always fires regardless of connection). This emit-before-local order satisfies SYNC-01.

    After all edits: run pio run to verify the build exits 0. Fix any compile errors before proceeding (common mistakes: missing closing braces, wrong string escaping, _suppressAction comparisons against const char* rather than String).
  </action>
  <verify>
    <automated>cd /Users/themightypong/Documents/PythonCode/Arena-Timer-Firmware-Standalone && pio run 2>&1 | tail -5</automated>
  </verify>
  <acceptance_criteria>
    - src/WebSocketClient.cpp contains the string: 42["timer_control" (confirm emit format is present in emitTimerControl)
    - src/WebSocketClient.cpp contains: _suppressAction = String(action) (suppression window set in emitTimerControl)
    - src/WebSocketClient.cpp contains: millis() + 500UL (exact suppression duration, not a variable)
    - src/WebSocketClient.cpp contains: _suppressAction.length() > 0 (suppression check is present in handleTimerUpdate)
    - src/WebSocketClient.cpp contains: _suppressAction = "" (one-shot consume is present)
    - src/WebSocketClient.cpp contains: request_timer_status",{"timer_id":1} (correct payload — not {} or null)
    - src/WebSocketClient.cpp contains: arr[0] == "timer_status" (timer_status branch in handleWebSocketEvent)
    - src/WebSocketClient.cpp contains: is_initial_sync (flag detection in reset branch)
    - src/WebSocketClient.cpp contains: is_heartbeat (heartbeat guard in start branch)
    - src/WebSocketClient.cpp contains: _initialSyncPending = false in the WStype_DISCONNECTED handler (verify by reading that case block)
    - src/WebSocketClient.cpp contains: setDuration and reset and start in the timer_status handler (in that order)
    - pio run exits 0 with no compiler errors or warnings about _suppressAction, _suppressUntilMs, or _initialSyncPending
  </acceptance_criteria>
  <done>
    Build succeeds. All five edits applied. emitTimerControl() emits before local timer call and sets suppression. handleTimerUpdate() suppresses echo at entry, guards heartbeats, requests timer_status on runtime start, sets _initialSyncPending on initial sync reset. handleWebSocketEvent() handles timer_status by applying time_left via setDuration+reset+start. _initialSyncPending resets on disconnect. SYNC-01, SYNC-02, SYNC-03 requirements satisfied.
  </done>
</task>

</tasks>

<threat_model>
## Trust Boundaries

| Boundary | Description |
|---|---|
| LAN → firmware | timer_update and timer_status events arrive from FightTimer server over WebSocket; firmware treats payloads as potentially malformed |
| firmware → LAN | timer_control and request_timer_status emitted by firmware; no authentication required (isolated arena LAN per REQUIREMENTS.md) |

## STRIDE Threat Register

| Threat ID | Category | Component | Disposition | Mitigation Plan |
|---|---|---|---|---|
| T-03-01 | Tampering | handleWebSocketEvent() timer_status branch | mitigate | ArduinoJson `\| 0` default for time_left field; if absent/wrong type defaults to 0; the `if (time_left > 0)` guard prevents setDuration(0,0,0)+reset+start from running on a missing field |
| T-03-02 | Denial of Service | handleTimerUpdate() echo loop | mitigate | SYNC-02 one-shot suppression directly addresses FightTimer broadcast echo re-triggering local timer; suppression window is 500ms action-matched |
| T-03-03 | Spoofing | Rogue FightTimer server on LAN | accept | Isolated arena LAN; unauthenticated control is explicit out-of-scope per REQUIREMENTS.md §Out of Scope; no credential exfiltration risk |
| T-03-04 | Denial of Service | handleTimerUpdate() start branch — heartbeat flood | mitigate | is_heartbeat guard added in start branch; returns early without emitting request_timer_status on FightTimer's 5-second heartbeat broadcasts; prevents 5s polling cycle |
</threat_model>

<verification>
After Task 2, confirm all three SYNC requirements are observable:

SYNC-01: Serial log shows "emitTimerControl: sent 42[\"timer_control\",{\"action\":\"start\"}]" BEFORE "Starting timer..." on a button press while connected. Offline: button press applies local timer with no emit log.

SYNC-02: Immediately after a button-triggered emit, a simulated FightTimer echo (same action) should log "Echo suppressed: start" and return without re-triggering the timer. A second FightTimer emit of the same action >500ms later should apply normally.

SYNC-03: Serial log shows "Runtime start: emitted request_timer_status" then "SYNC-03 applied: time_left=N" on a FightTimer-originated start. On initial connect sequence (reset with is_initial_sync: true followed by start), log shows "is_initial_sync: next start skips request_timer_status".

Build check: pio run exits 0 with no errors.
</verification>

<success_criteria>
- pio run exits 0 (no compile errors)
- include/WebSocketClient.h declares _suppressAction (String), _suppressUntilMs (unsigned long), _initialSyncPending (bool) in the private section
- src/WebSocketClient.cpp constructor initializes _suppressAction(""), _suppressUntilMs(0), _initialSyncPending(false)
- emitTimerControl() sends 42["timer_control",{"action":"..."}] before calling _timer->start/stop/reset
- emitTimerControl() sets _suppressAction and _suppressUntilMs = millis() + 500UL only when _connected
- handleTimerUpdate() suppression check is the first block after the null-action guard
- handleTimerUpdate() start branch guards is_heartbeat, calls _timer->start(), then either skips or emits request_timer_status with {"timer_id":1}
- handleTimerUpdate() reset branch sets _initialSyncPending = true when is_initial_sync is present
- handleWebSocketEvent() timer_status branch applies time_left via setDuration+reset+start in correct order
- WStype_DISCONNECTED handler clears _initialSyncPending
</success_criteria>

<output>
Create `.planning/phases/03-socket-io-integration/03-01-SUMMARY.md` when done
</output>

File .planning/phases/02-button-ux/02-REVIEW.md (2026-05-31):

---
phase: 02-button-ux
reviewed: 2026-05-31T00:00:00Z
depth: standard
files_reviewed: 7
files_reviewed_list:
  - include/ButtonHandler.h
  - src/ButtonHandler.cpp
  - include/WebSocketClient.h
  - src/WebSocketClient.cpp
  - include/TimerDisplay.h
  - src/TimerDisplay.cpp
  - src/main.cpp
findings:
  critical: 3
  warning: 4
  info: 3
  total: 10
status: issues_found
---

# Phase 02: Code Review Report

**Reviewed:** 2026-05-31
**Depth:** standard
**Files Reviewed:** 7
**Status:** issues_found

## Summary

Reviewed the Phase 2 button-UX implementation: ButtonHandler debounce state machine, TimerDisplay armed overlay, WebSocketClient emitTimerControl stub, and main.cpp wiring. The ButtonHandler logic and display overlay are structurally sound. Three blockers were found: an EEPROM buffer overwrite that corrupts memory when a stored string is exactly at the capped length, a hardcoded debug flag left `true` in production WebSocket code that floods Serial on every received message, and a missing `emitTimerControl("reset")` duration argument that resets to the wrong time when called from the button path. Four warnings cover a stop+reset ordering hazard, a stale `_b2.fell()` check in the DISARMED log condition, unused header members, and a layering violation where TimerDisplay directly includes Ethernet hardware headers.

---

## Critical Issues

### CR-01: EEPROM buf[len] write out-of-bounds when len == 127

**File:** `src/WebSocketClient.cpp:99-102` (host), `112-115` (path), `120-123` (namespace)

**Issue:** The read loop guards `i < 127` (host/path) or `i < 63` (namespace), but the null terminator is written as `buf[len]`, not `buf[i]` where `i` stopped. When the EEPROM-stored length byte is exactly 127 (host or path) or 63 (namespace), the loop reads 0 bytes (because `i < 127` is immediately false for `len == 127`), then writes `buf[127] = 0`, which is one past the end of the 128-byte stack buffer — a classic off-by-one stack corruption on RP2040.

Concrete scenario: a host string of exactly 100 characters is saved (saveSettings caps at 100, so `len == 100`). The loop copies bytes 0..99 fine. `buf[100] = 0` is safe. The real hazard is if corrupted EEPROM ever delivers a `len` value of 127 or higher. EEPROM.read() returns `uint8_t` (0-255), so any value ≥ 127 will write the null terminator past the buffer end.

**Fix:** Clamp the null write to the actual stop index, not the raw `len`:

```cpp
// Host
int len = EEPROM.read(1);
int actual = 0;
for (int i = 0; i < len && i < 127; i++) {
  buf[i] = EEPROM.read(2 + i);
  actual = i + 1;
}
buf[actual] = '\0';  // safe: actual is always 0..127 (within [128] buffer)

// Path (same pattern, cap 127)
// Namespace: cap to 63, buffer index always 0..63 (buf[128] is large enough)
```

Alternatively use `buf[min(len, 127)] = 0` making the bound explicit:

```cpp
buf[len < 127 ? len : 127] = '\0';
```

---

### CR-02: DEBUG_WEBSOCKET left `true` — verbose Serial flood in production

**File:** `src/WebSocketClient.cpp:4`

**Issue:** `#define DEBUG_WEBSOCKET true` — the comment on line 3 even admits "ENABLED temporarily for debugging". With this flag live, every received WebSocket message, every ping/pong, every disconnect event, and every JSON parse step prints to Serial. On an RP2040 with a connected display loop running at ~60 Hz and WebSocket traffic, this generates continuous Serial output that: (a) consumes significant CPU time, (b) fills any connected USB serial buffer, and (c) constitutes a regression from the intended production build. The code path covers `DEBUG_PRINTLN(data)` at line 332 which dumps the full raw payload of every inbound message.

**Fix:**

```cpp
// src/WebSocketClient.cpp line 4
#define DEBUG_WEBSOCKET false   // was: true
```

---

### CR-03: emitTimerControl("reset") does not set duration — resets to wrong time

**File:** `src/main.cpp:137`, `src/WebSocketClient.cpp:477-488`

**Issue:** When `stopResetPressed()` fires, main.cpp calls:
```cpp
wsClient->emitTimerControl("stop");
wsClient->emitTimerControl("reset");
```

`emitTimerControl("reset")` in WebSocketClient.cpp only calls `_timer->reset()` with no duration argument:
```cpp
} else if (strcmp(action, "reset") == 0) {
    _timer->reset();
}
```

Compare to the network path in `handleTimerUpdate` (lines 442-455), which first calls `_timer->setDuration(...)` with the server-provided minutes/seconds, then `_timer->reset()`. The local button path skips `setDuration`, so `reset()` restores the timer to whatever duration it was last given — which may be a partial or zero value if the timer has never been set via the network. After a cold boot where no server connection was made, the button reset will reset to 0:00 instead of the configured duration (e.g., 3:00).

**Fix:** `emitTimerControl` should read the timer's own current duration before resetting, ensuring idempotent local resets:

```cpp
} else if (strcmp(action, "reset") == 0) {
    // Preserve the current configured duration — do not wipe it
    Timer::Components dur = _timer->getDuration();
    _timer->setDuration(dur);   // no-op if already set, but makes intent explicit
    _timer->reset();
}
```

Or, if the design intent is "reset to the last set duration", verify that `Timer::reset()` already does this correctly and document the contract. If `Timer::reset()` already restores to the last `setDuration` value, CR-03 is a documentation gap rather than a behavior bug — but that contract is not visible from the reviewed files and must be confirmed.

---

## Warnings

### WR-01: stop() then reset() in same loop tick — ordering hazard

**File:** `src/main.cpp:136-138`

**Issue:**
```cpp
wsClient->emitTimerControl("stop");
wsClient->emitTimerControl("reset");
```

Both calls happen synchronously in the same loop() tick. `emitTimerControl("stop")` calls `_timer->stop()`. `emitTimerControl("reset")` calls `_timer->reset()`. If `Timer::reset()` internally also stops the timer (which is typical), the double-stop is harmless. But if `Timer::reset()` is supposed to restart from the set duration (common in countdown designs), calling `stop()` first and `reset()` second may leave the timer in the wrong state depending on state machine transitions.

More importantly, a future Phase 3 implementation is expected to emit Socket.IO events *and* call local. If stop+reset are emitted as two separate Socket.IO messages, the server may process them out of order or treat "stop" as a no-op if the timer is already stopped. Consider combining into a single `"stopreset"` action or making `reset()` imply `stop()` internally.

**Fix:** Consolidate to a single action that the Timer state machine handles atomically:

```cpp
if (buttonHandler.stopResetPressed()) {
  if (wsClient) {
    wsClient->emitTimerControl("stopreset"); // single atomic action
  }
}
```

And add `"stopreset"` handling in `emitTimerControl`.

---

### WR-02: DISARMED debug log condition uses stale Bounce2 `fell()` result

**File:** `src/ButtonHandler.cpp:59`

**Issue:**
```cpp
if (!_armed && was_armed && !_b1.fell()) { DEBUG_PRINTLN("DISARMED"); }
```

`_b1.fell()` on line 59 calls the Bounce2 `fell()` getter a second time after it was already consumed on line 48. Bounce2's `fell()` is edge-triggered — it returns `true` exactly once per `update()` call per falling edge. After line 48's `if (_b1.fell())` check fires, the internal flag is cleared. By line 59, `_b1.fell()` will always return `false`.

Result: the DISARMED log line is **never suppressed** when B1 and B2 are released simultaneously. The condition `!_b1.fell()` on line 59 is always true (because the flag was consumed), so DISARMED logs even in the simultaneous-press-release scenario the condition was trying to exclude.

**Fix:** Cache the B1 fell result at the top of poll():

```cpp
bool b1_fell = _b1.fell();
// ...
if (b1_fell) {
  if (_armed) { _stopResetPending = true; }
  else        { _startStopPending = true; }
}
// ...
if (!_armed && was_armed && !b1_fell) { DEBUG_PRINTLN("DISARMED"); }
```

---

### WR-03: Three unused private member variables in WebSocketClient

**File:** `include/WebSocketClient.h:50-52`

**Issue:** `_isSocketIO`, `_socketIOFallback`, and `_socketIOSessionId` are declared in the class but never assigned or read in `WebSocketClient.cpp`. The local variable `isSocketIO` (lowercase, stack-scoped) in `connect()` and `poll()` shadows the intent, but the member `_isSocketIO` is never written. On an embedded target this wastes a small amount of RAM (1 bool + 1 bool + String overhead ≈ 12+ bytes), and more importantly these ghost members mislead future maintainers about what state is being tracked.

**Fix:** Remove the three unused members from the header:

```cpp
// Remove these three lines from WebSocketClient.h:
bool _isSocketIO;
bool _socketIOFallback;
String _socketIOSessionId;
```

---

### WR-04: TimerDisplay includes Ethernet hardware header — layering violation

**File:** `src/TimerDisplay.cpp:7`

**Issue:** `#include <Ethernet_Generic.hpp>` is included directly in `TimerDisplay.cpp`. `TimerDisplay` is a display abstraction; it has no business depending on the Ethernet stack. The only consumer is `renderNetworkStatus()` (line 488), which calls `Ethernet.localIP()` and `Ethernet.linkStatus()`. This couples the display class to the network hardware, preventing unit testing or reuse on hardware without Ethernet, and creates a circular concern (display knows about network layer).

Additionally, `main.cpp` includes `<Ethernet_Generic.h>` (no `.hpp` extension) while `TimerDisplay.cpp` includes `<Ethernet_Generic.hpp>` — these may refer to the same file through include-guards, but the inconsistent include spelling is a fragile convention.

**Fix:** Move network status data into a struct passed into `renderNetworkStatus()`:

```cpp
// TimerDisplay.h
struct NetworkInfo {
  String ip;
  bool linkUp;
};
void renderNetworkStatus(const NetworkInfo& info);
```

Then remove `#include <Ethernet_Generic.hpp>` from `TimerDisplay.cpp`. Main.cpp fills the struct before calling the method.

---

## Info

### IN-01: `_color` member in TimerDisplay is written but never read

**File:** `include/TimerDisplay.h:131`, `src/TimerDisplay.cpp:54-56`

**Issue:** `_color` (uint16_t) is set by `setColor()` at line 54-56 and initialized in the constructor, but `getCurrentColor()` (lines 444-471) always computes the color from `_default_r/g/b` or thresholds — it never reads `_color`. `setColor()` appears in the public API but has no effect on the rendered output.

**Fix:** Either remove `_color` and make `setColor()` delegate to `setDefaultColor()`, or wire `_color` into `getCurrentColor()` as the fallback when no thresholds match. The current behavior silently discards calls to `setColor()`.

---

### IN-02: `wsClient` null-check repeated but initialization is unconditional

**File:** `src/main.cpp:135, 142, 154`

**Issue:** `wsClient` is assigned unconditionally at line 108 (`wsClient = new WebSocketClient(...)`). The repeated `if (wsClient)` guards in loop() can never be false unless `new` throws (which on bare-metal RP2040 without exceptions will hard-fault, not return nullptr). The guards are harmless but add visual noise and false implication that wsClient can be null in normal operation.

**Fix:** Either assert once in setup() or document why the null-check is retained as a defensive pattern.

---

### IN-03: `renderNetworkStatus()` is never called from main.cpp

**File:** `src/TimerDisplay.cpp:488`, `include/TimerDisplay.h:119`

**Issue:** `renderNetworkStatus()` is declared and implemented but no call site exists in the reviewed files. This is either dead code, or a planned feature that was declared prematurely. Combined with WR-04 (Ethernet coupling), the dead method pulls in the Ethernet dependency for no current benefit.

**Fix:** If this method is not wired into the button-hold network-view feature yet, remove or stub it and remove the `Ethernet_Generic.hpp` include until the feature is actually implemented.

---

_Reviewed: 2026-05-31_
_Reviewer: Claude (gsd-code-reviewer)_
_Depth: standard_

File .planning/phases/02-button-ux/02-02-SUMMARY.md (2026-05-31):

---
phase: 02-button-ux
plan: "02"
subsystem: firmware
tags: [timerdisplay, armed-overlay, button-routing, emittimercontrol, loop-wiring]

# Dependency graph
requires:
  - phase: 02-button-ux/02-01
    provides: ButtonHandler isArmed()/startStopPressed()/stopResetPressed() API, WebSocketClient emitTimerControl() stub

provides:
  - TimerDisplay setArmed(bool) with 1Hz yellow STOP? blink overlay when armed
  - main.cpp loop() wired with setArmed, stopResetPressed chord routing, startStopPressed toggle routing
  - Full Phase 2 button UX end-to-end: BTN-04, BTN-05, BTN-06, BTN-07 all active

affects: [03-fighttimer-sync]

# Tech tracking
tech-stack:
  added: []
  patterns:
    - Armed short-circuit in update(): check _armed at top of update() before all other rendering logic
    - Transition-aware setArmed(): reset _blink_state on both arm and disarm transitions for clean visual handoff
    - loop() call order: poll -> setArmed -> chord check -> toggle check -> update (D-11 anti-pattern prevented)
    - stopResetPressed before startStopPressed in loop(): chord reset takes priority per BTN-06

key-files:
  created: []
  modified:
    - include/TimerDisplay.h
    - src/TimerDisplay.cpp
    - src/main.cpp

key-decisions:
  - "Armed short-circuit returns early from update() before expired/paused/running logic — one-exit-path design prevents stale frames (D-10)"
  - "setArmed() resets _blink_state=true on both arm AND disarm transitions — prevents half-second dark gap on first blink and ensures normal rendering resumes visibly (Pitfall 3)"
  - "stopResetPressed checked before startStopPressed in loop() — ensures chord reset cannot be shadowed by start/stop event"
  - "isRunning() as sole toggle condition in startStopPressed branch — idle and paused both route to start via else, matching BTN-04 spec"

patterns-established:
  - "Armed overlay short-circuit: if (_armed) { blink logic; return; } at top of update()"
  - "Transition-aware boolean setter: check old vs new value, reset derived state on edges, then store"

requirements-completed: [BTN-04, BTN-05, BTN-06, BTN-07]

# Metrics
duration: 10min
completed: 2026-05-31
---

# Phase 02 Plan 02: TimerDisplay Armed Overlay + main.cpp Button Event Routing Summary

**TimerDisplay gains 1Hz warm-yellow STOP? blink overlay via setArmed() + update() short-circuit; main.cpp loop() wired with setArmed and full button event routing through emitTimerControl() — completing all four Phase 2 BTN requirements**

## Performance

- **Duration:** ~10 min
- **Started:** 2026-05-31T20:40:00Z
- **Completed:** 2026-05-31T20:50:00Z
- **Tasks:** 2
- **Files modified:** 3

## Accomplishments
- TimerDisplay.setArmed(bool) implemented with transition-aware blink state resets on both arm/disarm transitions
- update() gains armed short-circuit block at the top: 1Hz blink of warm yellow (255,200,0) "STOP?" at cursor(17,12) on 64x32 matrix
- main.cpp loop() reordered: setArmed immediately after poll(), stopResetPressed chord check before startStopPressed toggle, timerDisplay.update() after all button routing
- All emitTimerControl calls wrapped in if (wsClient) null-guard; no change to Ethernet or WebSocket polling order
- Full Phase 2 success criteria met: BTN-04 toggle, BTN-05 armed display, BTN-06 chord reset, BTN-07 yellow blink all active

## Task Commits

Each task was committed atomically:

1. **Task 1: TimerDisplay armed overlay** - `92e4019` (feat)
2. **Task 2: main.cpp button event routing** - `b32e037` (feat)

## Files Created/Modified
- `include/TimerDisplay.h` - Added void setArmed(bool armed) declaration (doxygen) + bool _armed private member
- `src/TimerDisplay.cpp` - Extended constructor init list with _armed(false); added setArmed() implementation; added armed short-circuit block in update() with color565(255,200,0), setCursor(17,12), "STOP?" print
- `src/main.cpp` - Replaced loop() body with Phase 2 wiring: setArmed after poll(), chord/toggle event routing, update() after routing

## Decisions Made
- setArmed() resets _blink_state=true on disarm transition (not just arm) — ensures normal timer rendering resumes fully visible with no half-cycle dark gap
- _matrix.setFont(NULL) explicit in armed block — prevents GFX custom font from distorting "STOP?" layout (Open Question 1 from RESEARCH.md resolved conservatively)
- stopResetPressed branch checked first in loop() — chord reset takes logical priority; prevents race between the two one-shot flags in the same poll cycle
- isRunning()-only toggle condition — else covers both idle and paused states, matching BTN-04 intent that paused → start is a resume

## Deviations from Plan

None - plan executed exactly as written. All threat model mitigations implemented: T-02-04 (setArmed before update), T-02-05 (blink state reset on disarm).

## Issues Encountered
None.

## User Setup Required
None - no external service configuration required.

## Next Phase Readiness
- All four Phase 2 button UX requirements (BTN-04/05/06/07) are fully active
- Phase 3 (03-fighttimer-sync) can consume emitTimerControl seam: prepend Socket.IO emit without renaming the method
- Hardware verification: hold Button 2 >= 400ms to see STOP? blink; release to return to normal; hold B2 + press B1 for chord reset; press B1 alone to toggle start/stop

## Self-Check: PASSED

- include/TimerDisplay.h: void setArmed(bool armed) present (grep count: 2 — declaration + doxygen reference)
- include/TimerDisplay.h: bool _armed private member present
- src/TimerDisplay.cpp: _armed(false) in constructor init list
- src/TimerDisplay.cpp: void TimerDisplay::setArmed(bool armed) implementation present
- src/TimerDisplay.cpp: color565(255, 200, 0) present in armed block
- src/TimerDisplay.cpp: setCursor(17, 12) present in armed block
- src/TimerDisplay.cpp: "STOP?" print present in armed block
- src/main.cpp: timerDisplay.setArmed(buttonHandler.isArmed()) present (count: 1)
- src/main.cpp: stopResetPressed present (count: 1)
- src/main.cpp: startStopPressed present (count: 1)
- src/main.cpp: emitTimerControl calls present (count: 4 — stop+reset in chord, stop+start in toggle)
- src/main.cpp: timerDisplay.getTimer().isRunning() as toggle condition
- pio run exits 0 (SUCCESS)
- Commits 92e4019 and b32e037 confirmed in git log

---
*Phase: 02-button-ux*
*Completed: 2026-05-31*

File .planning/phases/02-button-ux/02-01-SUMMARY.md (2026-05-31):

---
phase: 02-button-ux
plan: "01"
subsystem: firmware
tags: [buttonhandler, bounce2, armed-state-machine, websocketclient, timer-control]

# Dependency graph
requires:
  - phase: 01-buttonhandler-foundation
    provides: ButtonHandler class scaffold with Bounce2 debounce, Phase 1 poll() with BTN1/BTN2 fell diagnostics
provides:
  - ButtonHandler armed state machine with isArmed(), startStopPressed(), stopResetPressed() public API
  - WebSocketClient emitTimerControl(const char* action) stub dispatching to _timer methods
affects: [02-02, 03-fighttimer-sync]

# Tech tracking
tech-stack:
  added: []
  patterns:
    - One-shot flag pattern: reset _startStopPending/_stopResetPending at top of poll() before evaluation
    - Ordered arm evaluation: arm check before Button 1 routing prevents 400ms chord misfire
    - strcmp dispatch to _timer: emitTimerControl reuses handleTimerUpdate() dispatch pattern

key-files:
  created: []
  modified:
    - include/ButtonHandler.h
    - src/ButtonHandler.cpp
    - include/WebSocketClient.h
    - src/WebSocketClient.cpp

key-decisions:
  - "One-shot flags reset at top of poll() before any conditional — prevents double-fire if accessor called multiple times per cycle (T-02-01)"
  - "Arm check placed before _b1.fell() routing — prevents first chord at exactly 400ms from misfiring as start/stop (T-02-02)"
  - "emitTimerControl Phase 2 stub calls _timer directly; Phase 3 prepends Socket.IO emit without renaming (D-05)"
  - "DEBUG_BUTTONHANDLER set to false; Phase 2 diagnostic messages replace Phase 1 BTN1/BTN2 fell output (D-12)"

patterns-established:
  - "Ordered poll() evaluation: update() -> reset flags -> arm check -> disarm check -> B1 routing"
  - "emitTimerControl seam pattern: Phase 2 local stub, Phase 3 prepends network emit"

requirements-completed: [BTN-04, BTN-05, BTN-06]

# Metrics
duration: 5min
completed: 2026-05-31
---

# Phase 02 Plan 01: ButtonHandler Armed State Machine + emitTimerControl Stub Summary

**ButtonHandler gains armed state machine with three-method event API (isArmed/startStopPressed/stopResetPressed) backed by Bounce2 hold-duration detection; WebSocketClient gains emitTimerControl strcmp dispatch stub wired to _timer directly as Phase 3 seam**

## Performance

- **Duration:** ~5 min
- **Started:** 2026-05-31T20:33:00Z
- **Completed:** 2026-05-31T20:38:04Z
- **Tasks:** 2
- **Files modified:** 4

## Accomplishments
- ButtonHandler exposes full armed-state event API: isArmed() persistent, startStopPressed()/stopResetPressed() one-shot per poll cycle
- Armed state machine in poll() with correct ordering: arm check before B1 routing prevents chord timing edge case
- Phase 1 BTN1 fell / BTN2 fell diagnostics removed; replaced with Phase 2 state messages ARMED/DISARMED/START_STOP/STOP_RESET
- WebSocketClient emitTimerControl stub ready for Plan 02 main.cpp wiring and Plan 03 network upgrade

## Task Commits

Each task was committed atomically:

1. **Task 1: ButtonHandler state machine** - `d391684` (feat)
2. **Task 2: WebSocketClient emitTimerControl stub** - `9a14570` (feat)

## Files Created/Modified
- `include/ButtonHandler.h` - Added isArmed(), startStopPressed(), stopResetPressed() declarations; _armed, _startStopPending, _stopResetPending private members
- `src/ButtonHandler.cpp` - Rewrote poll() with ordered state machine; extended constructor init list; removed Phase 1 diagnostics; added three const accessor one-liners
- `include/WebSocketClient.h` - Added emitTimerControl(const char* action) declaration in public section after // Status block
- `src/WebSocketClient.cpp` - Added emitTimerControl() implementation at end of file using strcmp dispatch to _timer->start()/stop()/reset()

## Decisions Made
- One-shot flags (_startStopPending, _stopResetPending) stored as bool members reset at top of poll() — simpler than deriving from Bounce2 state at accessor call time, matches D-02 idiom
- DEBUG_BUTTONHANDLER set to false (not repurposed to true) — Phase 2 diagnostics are optional; leaving off reduces serial noise in production
- was_armed local variable added in poll() to enable ARMED/DISARMED transition detection for debug output without separate tracking member

## Deviations from Plan

None - plan executed exactly as written. Threat model mitigations T-02-01 (one-shot flag reset) and T-02-02 (arm check ordering) both implemented as specified.

## Issues Encountered
None.

## User Setup Required
None - no external service configuration required.

## Next Phase Readiness
- Plan 02-02 can immediately consume ButtonHandler event API and emitTimerControl seam
- main.cpp loop() wiring (setArmed + event routing), TimerDisplay armed overlay (D-09 through D-11) are the remaining Phase 2 deliverables
- No blockers; all four contract methods (isArmed, startStopPressed, stopResetPressed, emitTimerControl) are live and build cleanly

## Self-Check: PASSED

- include/ButtonHandler.h exists with 3 public methods + 3 private members
- src/ButtonHandler.cpp has ordered poll() + 3 accessor one-liners
- include/WebSocketClient.h has emitTimerControl declaration
- src/WebSocketClient.cpp has emitTimerControl implementation
- pio run exits 0 (SUCCESS)
- No BTN1 fell / BTN2 fell in ButtonHandler.cpp
- Commits d391684 and 9a14570 confirmed in git log

---
*Phase: 02-button-ux*
*Completed: 2026-05-31*

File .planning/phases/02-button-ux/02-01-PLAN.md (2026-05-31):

---
phase: "02-button-ux"
plan: "01"
type: execute
wave: 1
depends_on: []
files_modified:
  - include/ButtonHandler.h
  - src/ButtonHandler.cpp
  - include/WebSocketClient.h
  - src/WebSocketClient.cpp
autonomous: true
requirements:
  - BTN-04
  - BTN-05
  - BTN-06

must_haves:
  truths:
    - "ButtonHandler exposes isArmed() (persistent), startStopPressed() (one-shot), stopResetPressed() (one-shot)"
    - "Armed state is entered when Button 2 has been held LOW for >=400ms and is still held"
    - "Armed state is cleared when Button 2 rises (rose()); releasing Button 2 alone causes no timer action"
    - "Button 1 fell while disarmed sets _startStopPending=true; while armed sets _stopResetPending=true"
    - "One-shot flags are reset to false at the top of every poll() call — before any evaluation"
    - "Arm check (set _armed=true) evaluates before Button 1 routing inside poll() — chord edge case safe"
    - "Phase 1 DEBUG_PRINTLN BTN1/BTN2 fell diagnostics are removed from poll() per D-12"
    - "WebSocketClient declares and implements emitTimerControl(const char* action)"
    - "emitTimerControl dispatches to _timer->start() / _timer->stop() / _timer->reset() via strcmp"
    - "pio run completes with 0 errors after these changes"
  artifacts:
    - path: "include/ButtonHandler.h"
      provides: "ButtonHandler class declaration with armed state machine API"
      exports: ["isArmed()", "startStopPressed()", "stopResetPressed()"]
    - path: "src/ButtonHandler.cpp"
      provides: "Armed state machine implementation"
      contains: "_b2.currentDuration() >= 400"
    - path: "include/WebSocketClient.h"
      provides: "emitTimerControl declaration"
      contains: "void emitTimerControl(const char* action)"
    - path: "src/WebSocketClient.cpp"
      provides: "emitTimerControl stub dispatching to _timer methods"
      contains: "strcmp(action, \"start\")"
  key_links:
    - from: "src/ButtonHandler.cpp poll()"
      to: "_startStopPending / _stopResetPending flags"
      via: "bool flags set inside poll(), read by main.cpp accessors"
      pattern: "_startStopPending = (false|true)"
    - from: "src/WebSocketClient.cpp emitTimerControl()"
      to: "_timer->start() / _timer->stop() / _timer->reset()"
      via: "strcmp dispatch on action string"
      pattern: "strcmp\\(action"
---

<objective>
Implement the ButtonHandler armed state machine (BTN-04, BTN-05, BTN-06) and the WebSocketClient timer control stub (D-05).

ButtonHandler gains three public accessors — `isArmed()`, `startStopPressed()`, `stopResetPressed()` — backed by an internal state machine inside `poll()` that tracks Button 2 hold duration, armed state, and one-shot event flags. WebSocketClient gains `emitTimerControl(const char* action)`, the Phase 2 stub that calls `_timer` directly and serves as the Phase 3 seam.

Purpose: Establishes the event API that main.cpp will consume in Plan 02. All four BTN-04/05/06 hardware behaviors are encoded here. D-12 cleanup also happens here.

Output: Modified ButtonHandler.h/cpp and WebSocketClient.h/cpp. Project must still build cleanly (`pio run`).
</objective>

<execution_context>
@/Users/themightypong/.claude/get-shit-done/workflows/execute-plan.md
@/Users/themightypong/.claude/get-shit-done/templates/summary.md
</execution_context>

<context>
@.planning/ROADMAP.md
@.planning/REQUIREMENTS.md
@.planning/phases/02-button-ux/02-CONTEXT.md
@.planning/phases/02-button-ux/02-RESEARCH.md
@.planning/phases/02-button-ux/02-PATTERNS.md
</context>

<tasks>

<task type="auto">
  <name>Task 1: ButtonHandler state machine — headers and implementation (D-01 through D-04, D-12, BTN-04, BTN-05, BTN-06)</name>
  <files>include/ButtonHandler.h, src/ButtonHandler.cpp</files>
  <read_first>
    - include/ButtonHandler.h — current class declaration (Phase 1 base to extend)
    - src/ButtonHandler.cpp — current poll() implementation with Phase 1 diagnostics to replace
    - .planning/phases/02-button-ux/02-PATTERNS.md §ButtonHandler.h and §ButtonHandler.cpp — exact code patterns, member names, constructor init list, accessor one-liners
    - .planning/phases/02-button-ux/02-RESEARCH.md §Pattern 1 — armed state machine poll() pattern with ordered evaluation
  </read_first>
  <action>
    Extend include/ButtonHandler.h:
    - After `void poll();`, add three public method declarations using `/// @brief` doxygen style (per D-01, D-02):
      `bool isArmed() const;` — persistent state
      `bool startStopPressed() const;` — one-shot per poll cycle, fires when Button 1 fell while disarmed
      `bool stopResetPressed() const;` — one-shot per poll cycle, fires when Button 1 fell while armed (D-03)
    - After `Bounce _b2;` in private section, add three private members:
      `bool _armed;`, `bool _startStopPending;`, `bool _stopResetPending;`

    Rewrite src/ButtonHandler.cpp:
    - Constructor initializer list: extend existing `: _pin1(pin1), _pin2(pin2)` to add `, _armed(false), _startStopPending(false), _stopResetPending(false)` before `{}`.
    - Keep the `#define DEBUG_BUTTONHANDLER` macro block at the top; set flag to `false` and update the diagnostic messages to Phase 2 state transitions: `"ARMED"`, `"DISARMED"`, `"START_STOP"`, `"STOP_RESET"` (per D-12 — remove the Phase 1 `BTN1 fell` / `BTN2 fell` output).
    - Replace the entire body of `poll()` with the ordered state machine (per D-04 and Pitfall 4 — arm evaluation MUST precede Button 1 routing):
      1. Call `_b1.update()` then `_b2.update()`.
      2. Reset one-shot flags at the very top: `_startStopPending = false; _stopResetPending = false;` (prevents double-fire per Pitfall 2).
      3. Arm check: `if (_b2.read() == LOW && _b2.currentDuration() >= 400) { _armed = true; }` — sets armed once threshold crossed while still held.
      4. Disarm on release: `if (_b2.rose()) { _armed = false; }` — releasing Button 2 always disarms (BTN-05: no timer action on release).
      5. Button 1 routing (AFTER arm state is settled): `if (_b1.fell()) { if (_armed) { _stopResetPending = true; } else { _startStopPending = true; } }` (per D-03).
      6. Optional DEBUG_PRINTLN calls guarded by `DEBUG_BUTTONHANDLER`: `"ARMED"` on arm transition, `"DISARMED"` on disarm, `"STOP_RESET"` when `_stopResetPending` set, `"START_STOP"` when `_startStopPending` set.
    - Add three const accessor implementations as one-liners after the existing `begin()` implementation:
      `bool ButtonHandler::isArmed() const { return _armed; }`
      `bool ButtonHandler::startStopPressed() const { return _startStopPending; }`
      `bool ButtonHandler::stopResetPressed() const { return _stopResetPending; }`
  </action>
  <verify>
    <automated>cd /Users/themightypong/Documents/PythonCode/Arena-Timer-Firmware-Standalone && pio run 2>&1 | tail -5</automated>
  </verify>
  <acceptance_criteria>
    - include/ButtonHandler.h public section contains `bool isArmed() const;`, `bool startStopPressed() const;`, `bool stopResetPressed() const;`
    - include/ButtonHandler.h private section contains `bool _armed;`, `bool _startStopPending;`, `bool _stopResetPending;`
    - src/ButtonHandler.cpp constructor initializer list contains `_armed(false)`, `_startStopPending(false)`, `_stopResetPending(false)`
    - src/ButtonHandler.cpp poll() body contains `_startStopPending = false;` and `_stopResetPending = false;` before any conditional
    - src/ButtonHandler.cpp poll() contains `_b2.currentDuration() >= 400` for arm detection
    - src/ButtonHandler.cpp poll() contains `_b2.rose()` for disarm detection
    - src/ButtonHandler.cpp poll() contains `_b1.fell()` with `_armed` branching
    - src/ButtonHandler.cpp does NOT contain `BTN1 fell` or `BTN2 fell` (Phase 1 diagnostics removed per D-12)
    - `pio run` exits 0
  </acceptance_criteria>
  <done>ButtonHandler exposes the full armed-state event API. Phase 1 diagnostics removed. Project builds.</done>
</task>

<task type="auto">
  <name>Task 2: WebSocketClient emitTimerControl stub (D-05, D-07)</name>
  <files>include/WebSocketClient.h, src/WebSocketClient.cpp</files>
  <read_first>
    - include/WebSocketClient.h — current public section structure (uses #ifndef guard, not #pragma once; keep as-is)
    - src/WebSocketClient.cpp — handleTimerUpdate() strcmp dispatch pattern (lines ~432–456); add new method at end of file
    - .planning/phases/02-button-ux/02-PATTERNS.md §WebSocketClient.h and §WebSocketClient.cpp — exact insertion point and implementation pattern
    - .planning/phases/02-button-ux/02-RESEARCH.md §Pattern 3 — emitTimerControl stub
  </read_first>
  <action>
    Modify include/WebSocketClient.h:
    - In the public section, after the `// Status` comment block (containing `getStatus()` and `getServerUrl()`), add a new comment group and declaration:
      `// Timer control (Phase 2: local stub; Phase 3: emits Socket.IO then calls local)`
      `void emitTimerControl(const char* action);`
    - Do not add any new private members — `_timer` pointer already exists.

    Modify src/WebSocketClient.cpp:
    - At the end of the file, add the `emitTimerControl()` implementation using the same `strcmp` dispatch pattern as `handleTimerUpdate()`:
      - `if (strcmp(action, "start") == 0)` → `DEBUG_PRINTLN("emitTimerControl: start"); _timer->start();`
      - `else if (strcmp(action, "stop") == 0)` → `DEBUG_PRINTLN("emitTimerControl: stop"); _timer->stop();`
      - `else if (strcmp(action, "reset") == 0)` → `DEBUG_PRINTLN("emitTimerControl: reset"); _timer->reset();`
    - Use the same `DEBUG_PRINTLN` macro already in the file. Action strings are `"start"`, `"stop"`, `"reset"` per D-07 — these match FightTimer's Socket.IO vocabulary exactly.
    - Note: `reset()` in this stub does NOT set duration from JSON (unlike the network path). The timer retains its current duration on reset — correct for chord-reset UX.
  </action>
  <verify>
    <automated>cd /Users/themightypong/Documents/PythonCode/Arena-Timer-Firmware-Standalone && pio run 2>&1 | tail -5</automated>
  </verify>
  <acceptance_criteria>
    - include/WebSocketClient.h public section contains `void emitTimerControl(const char* action);`
    - src/WebSocketClient.cpp contains `void WebSocketClient::emitTimerControl(const char* action)`
    - src/WebSocketClient.cpp emitTimerControl body contains `strcmp(action, "start")`, `strcmp(action, "stop")`, `strcmp(action, "reset")`
    - src/WebSocketClient.cpp emitTimerControl calls `_timer->start()`, `_timer->stop()`, `_timer->reset()` in respective branches
    - `pio run` exits 0
  </acceptance_criteria>
  <done>WebSocketClient has the emitTimerControl stub. Project builds. Phase 3 can replace the body with network emit prepended to the same local calls.</done>
</task>

</tasks>

<threat_model>
## Trust Boundaries

| Boundary | Description |
|---|---|
| Button hardware → ButtonHandler | Active-low GPIO signals processed by Bounce2; only source of input in Phase 2 |
| main.cpp → emitTimerControl | Hardcoded literal string callers only; no external input reaches this method in Phase 2 |

## STRIDE Threat Register

| Threat ID | Category | Component | Disposition | Mitigation Plan |
|---|---|---|---|---|
| T-02-01 | Tampering | ButtonHandler::poll() one-shot flags | mitigate | Clear `_startStopPending` and `_stopResetPending` at top of `poll()` before any evaluation — prevents double-fire if accessor called multiple times per cycle |
| T-02-02 | Tampering | Chord timing: arm check order in poll() | mitigate | Arm evaluation (`_b2.currentDuration() >= 400`) placed before `_b1.fell()` routing — prevents first chord at exactly 400ms from misfiring as start/stop |
| T-02-03 | Tampering | emitTimerControl null action pointer | accept | All callers in Phase 2 pass compile-time string literals; `wsClient` null-guarded in main.cpp; null dereference risk is zero in Phase 2 scope |
| T-02-SC | Tampering | npm/pip/cargo installs | accept | No new packages in Phase 2; platformio.ini unchanged; no install tasks |
</threat_model>

<verification>
After both tasks complete:
- `pio run` exits 0
- `grep -c "BTN1 fell\|BTN2 fell" src/ButtonHandler.cpp` returns 0 (Phase 1 diagnostics removed)
- `grep -c "isArmed\|startStopPressed\|stopResetPressed" include/ButtonHandler.h` returns 3
- `grep -c "emitTimerControl" include/WebSocketClient.h` returns 1
- `grep -c "emitTimerControl" src/WebSocketClient.cpp` returns 1 (definition only; calls added in Plan 02)
</verification>

<success_criteria>
ButtonHandler exposes a clean three-method event API backed by an internal state machine that owns armed state (D-04). Phase 1 diagnostics removed (D-12). WebSocketClient has `emitTimerControl()` stub ready for Phase 3 seam (D-05). Project builds without errors. Plan 02 can consume these contracts without clarification.
</success_criteria>

<output>
Create `.planning/phases/02-button-ux/02-01-SUMMARY.md` when done.
</output>

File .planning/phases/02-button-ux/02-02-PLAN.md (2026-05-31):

---
phase: "02-button-ux"
plan: "02"
type: execute
wave: 2
depends_on:
  - "02-01"
files_modified:
  - include/TimerDisplay.h
  - src/TimerDisplay.cpp
  - src/main.cpp
autonomous: true
requirements:
  - BTN-04
  - BTN-05
  - BTN-06
  - BTN-07

must_haves:
  truths:
    - "TimerDisplay has a setArmed(bool) public method that stores the armed flag and manages blink state on transitions"
    - "When armed, TimerDisplay::update() short-circuits normal rendering and blinks yellow STOP? at 1Hz (500ms on/500ms off)"
    - "When armed, the STOP? text uses color565(255, 200, 0) (warm yellow), default NULL font, size 1, centered at x=17 y=12 on the 64x32 matrix"
    - "On arm transition (false->true), _blink_state=true and _last_blink_ms=millis() are reset for a clean first blink cycle"
    - "On disarm transition (true->false), _blink_state=true is reset so normal rendering resumes visibly immediately"
    - "main.cpp loop() calls timerDisplay.setArmed(buttonHandler.isArmed()) immediately after buttonHandler.poll()"
    - "main.cpp routes stopResetPressed() to wsClient->emitTimerControl(stop) then emitTimerControl(reset) per D-06"
    - "main.cpp routes startStopPressed() to emitTimerControl(stop) when timer isRunning(), emitTimerControl(start) otherwise per D-08"
    - "All wsClient->emitTimerControl() calls in loop() are wrapped with if (wsClient) null-guard"
    - "timerDisplay.update() is called after setArmed() and after all button event routing per D-11 anti-pattern"
    - "pio run completes with 0 errors"
  artifacts:
    - path: "include/TimerDisplay.h"
      provides: "setArmed(bool) declaration and _armed private member"
      contains: "void setArmed(bool armed)"
    - path: "src/TimerDisplay.cpp"
      provides: "setArmed() implementation + armed short-circuit in update()"
      contains: "color565(255, 200, 0)"
    - path: "src/main.cpp"
      provides: "Button event routing and armed display wiring in loop()"
      contains: "emitTimerControl"
  key_links:
    - from: "src/main.cpp loop()"
      to: "timerDisplay.setArmed()"
      via: "buttonHandler.isArmed() return value"
      pattern: "setArmed\\(buttonHandler\\.isArmed\\(\\)\\)"
    - from: "src/TimerDisplay.cpp update()"
      to: "STOP? rendering block"
      via: "_armed early-return guard"
      pattern: "if \\(_armed\\)"
    - from: "src/main.cpp loop()"
      to: "wsClient->emitTimerControl()"
      via: "startStopPressed() / stopResetPressed() one-shot flags"
      pattern: "emitTimerControl\\("
---

<objective>
Wire the Phase 2 button UX end-to-end: add the armed display overlay to TimerDisplay and route button events in main.cpp through emitTimerControl() (D-09 through D-11, D-06, D-08, BTN-07).

TimerDisplay gains `setArmed(bool)` and an armed short-circuit block at the top of `update()` that renders yellow "STOP?" at 1Hz. main.cpp loop() is updated to call `setArmed()` each iteration and dispatch `startStopPressed()` / `stopResetPressed()` through `wsClient->emitTimerControl()`.

Purpose: Completes the full button UX. All four BTN-04/05/06/07 behaviors are active after this plan. The project is in a shippable state for Phase 2.

Output: Modified TimerDisplay.h/cpp and main.cpp. Full `pio run` must pass.
</objective>

<execution_context>
@/Users/themightypong/.claude/get-shit-done/workflows/execute-plan.md
@/Users/themightypong/.claude/get-shit-done/templates/summary.md
</execution_context>

<context>
@.planning/ROADMAP.md
@.planning/REQUIREMENTS.md
@.planning/phases/02-button-ux/02-CONTEXT.md
@.planning/phases/02-button-ux/02-RESEARCH.md
@.planning/phases/02-button-ux/02-PATTERNS.md
@.planning/phases/02-button-ux/02-01-SUMMARY.md
</context>

<tasks>

<task type="auto">
  <name>Task 1: TimerDisplay armed overlay — setArmed() + update() short-circuit (D-09, D-10, D-11, BTN-07)</name>
  <files>include/TimerDisplay.h, src/TimerDisplay.cpp</files>
  <read_first>
    - include/TimerDisplay.h — current class declaration, specifically the public method block around update() (lines ~103–107) and the private blink members block (lines ~136–138); look for existing _last_blink_ms, _blink_state, _was_expired
    - src/TimerDisplay.cpp — constructor initializer list (add _armed(false) at end), getTimer() method location (setArmed() goes after it, before update()), update() opening lines (armed short-circuit inserts after `unsigned long current_ms = millis();`), the expired-blink pattern and showMessage() fill+cursor+print+show pattern to reuse
    - .planning/phases/02-button-ux/02-PATTERNS.md §TimerDisplay.h and §TimerDisplay.cpp — exact insertion points, setArmed() implementation with blink reset logic, armed overlay block with x/y cursor values
    - .planning/phases/02-button-ux/02-RESEARCH.md §Pitfall 3 — why blink state must reset on both arm and disarm transitions
  </read_first>
  <action>
    Modify include/TimerDisplay.h:
    - Before the `/// @brief Update and draw the timer` declaration, add the setArmed declaration with doxygen comment:
      `/// @brief Set armed overlay mode. When true, displays yellow "STOP?" blink at 1Hz.`
      `/// Call each loop() with buttonHandler.isArmed() before update().`
      `void setArmed(bool armed);`
    - In the private section, after `bool _was_expired;`, add:
      `bool _armed; // Armed overlay flag — set by main.cpp each loop via setArmed()`

    Modify src/TimerDisplay.cpp:
    - Constructor initializer list: append `, _armed(false)` at the end of the existing list (after `_was_expired(false)`), before the `{` that opens the constructor body. The full list ends: `_was_expired(false), _armed(false) {`.
    - Add `setArmed()` implementation after the `getTimer()` function and before `update()`. Implement the transition-aware setter per D-11 and Pitfall 3:
      - On transition false→true (armed && !_armed): set `_blink_state = true` and `_last_blink_ms = millis()` — clean first blink cycle
      - On transition true→false (!armed && _armed): set `_blink_state = true` — normal rendering starts visible immediately
      - Then set `_armed = armed;`
    - In `update()`, immediately after `unsigned long current_ms = millis();`, add the armed short-circuit block per D-10:
      - `if (_armed) {` opens the block
      - Blink toggle: `if (current_ms - _last_blink_ms >= 500) { _blink_state = !_blink_state; _last_blink_ms = current_ms; }`
      - `_matrix.fillScreen(0);`
      - `if (_blink_state) {` renders text:
        - `_matrix.setFont(NULL);` — force default 5x7 font (same as showMessage() pattern; prevents GFX font sizing issues per Open Question 1)
        - `_matrix.setTextSize(1);`
        - `_matrix.setTextColor(_matrix.color565(255, 200, 0));` — warm yellow per BTN-07 (255, 200, 0 distinguishes from white timer text and red/green threshold colors)
        - `_matrix.setCursor(17, 12);` — x=17 centers 30px ("STOP?" at 5x6px/char) on 64px width; y=12 centers 7px glyph on 32px height
        - `_matrix.print("STOP?");`
      - `}`  (closes if _blink_state)
      - `_matrix.show();`
      - `return;` — skip all existing expired/paused/running logic below
      - `}` (closes if _armed)
  </action>
  <verify>
    <automated>cd /Users/themightypong/Documents/PythonCode/Arena-Timer-Firmware-Standalone && pio run 2>&1 | tail -5</automated>
  </verify>
  <acceptance_criteria>
    - include/TimerDisplay.h public section contains `void setArmed(bool armed);`
    - include/TimerDisplay.h private section contains `bool _armed;`
    - src/TimerDisplay.cpp constructor initializer list contains `_armed(false)`
    - src/TimerDisplay.cpp contains `void TimerDisplay::setArmed(bool armed)`
    - src/TimerDisplay.cpp setArmed() body contains `_blink_state = true` in both transition branches (arm and disarm)
    - src/TimerDisplay.cpp update() contains `if (_armed) {` block before the existing expired/blink logic
    - src/TimerDisplay.cpp update() armed block contains `color565(255, 200, 0)`
    - src/TimerDisplay.cpp update() armed block contains `_matrix.setCursor(17, 12)`
    - src/TimerDisplay.cpp update() armed block contains `_matrix.print("STOP?")`
    - src/TimerDisplay.cpp update() armed block ends with `return;`
    - `pio run` exits 0
  </acceptance_criteria>
  <done>TimerDisplay shows yellow blinking "STOP?" when armed, returns to normal timer display on disarm. Blink state is clean on both transitions. Project builds.</done>
</task>

<task type="auto">
  <name>Task 2: main.cpp button event routing (D-06, D-08, BTN-04, BTN-05, BTN-06)</name>
  <files>src/main.cpp</files>
  <read_first>
    - src/main.cpp — current loop() body (lines ~130–139): shows existing call order (buttonHandler.poll(), timerDisplay.update(), Ethernet.maintain(), WebServer::handleClient(), wsClient->poll()); note wsClient null-guard pattern
    - include/Timer.h — isRunning(), isIdle(), isPaused() signatures; confirm isRunning() is the correct branch for "stop" (Pitfall 5: else branch covers both idle and paused → "start")
    - .planning/phases/02-button-ux/02-PATTERNS.md §main.cpp — full loop() replacement showing the exact new call order and nested null-guard structure
    - .planning/phases/02-button-ux/02-RESEARCH.md §Pattern 4 — main.cpp button event routing and toggle logic
  </read_first>
  <action>
    Replace the loop() body in src/main.cpp with the Phase 2 wiring (per D-06, D-08). The new call order is mandatory — do not reorder:

    1. `buttonHandler.poll();` — unchanged, stays first
    2. `timerDisplay.setArmed(buttonHandler.isArmed());` — IMMEDIATELY after poll() per D-09; must come before update()
    3. Chord reset block (stopResetPressed check BEFORE startStopPressed — stopReset takes priority per BTN-06):
       ```
       if (buttonHandler.stopResetPressed()) {
         if (wsClient) {
           wsClient->emitTimerControl("stop");
           wsClient->emitTimerControl("reset");
         }
       }
       ```
       Two sequential calls: "stop" then "reset" — pre-wires Phase 3 two-event sequence; `_timer->stop()` is a no-op when already stopped so this is safe per the resolved Open Question 2 in RESEARCH.md.
    4. Start/stop toggle block (per D-08 — toggle logic lives here, reads timer state):
       ```
       if (buttonHandler.startStopPressed()) {
         if (wsClient) {
           if (timerDisplay.getTimer().isRunning()) {
             wsClient->emitTimerControl("stop");
           } else {
             wsClient->emitTimerControl("start");
           }
         }
       }
       ```
       Toggle condition: `isRunning()` → "stop", else (idle OR paused) → "start" (per Pitfall 5 — else covers both first-press and resume).
    5. `timerDisplay.update();` — after setArmed() and after all button routing
    6. `Ethernet.maintain();` — unchanged
    7. `WebServer::handleClient(timerDisplay);` — unchanged
    8. `if (wsClient) { wsClient->poll(); }` — unchanged

    All `wsClient->emitTimerControl()` calls are inside `if (wsClient)` guards matching the existing null-guard pattern in the file.
  </action>
  <verify>
    <automated>cd /Users/themightypong/Documents/PythonCode/Arena-Timer-Firmware-Standalone && pio run 2>&1 | tail -5</automated>
  </verify>
  <acceptance_criteria>
    - src/main.cpp loop() contains `timerDisplay.setArmed(buttonHandler.isArmed());`
    - src/main.cpp loop() contains `buttonHandler.stopResetPressed()` check
    - src/main.cpp loop() contains `buttonHandler.startStopPressed()` check
    - src/main.cpp loop() contains `wsClient->emitTimerControl("stop")` and `wsClient->emitTimerControl("reset")` inside the stopResetPressed branch
    - src/main.cpp loop() contains `wsClient->emitTimerControl("start")` and `wsClient->emitTimerControl("stop")` inside the startStopPressed branch
    - src/main.cpp loop() contains `timerDisplay.getTimer().isRunning()` as the toggle condition
    - src/main.cpp loop() has `timerDisplay.update()` AFTER `timerDisplay.setArmed(...)` (not before)
    - All `wsClient->emitTimerControl()` calls are inside `if (wsClient) {` blocks
    - `pio run` exits 0
    - <human-check>Hold Button 2 for >= 400ms — matrix displays yellow "STOP?" blinking. Release Button 2 — matrix returns to normal timer display with no state change. Then hold Button 2 again, press Button 1 while holding — timer resets. Separately, press Button 1 alone: RESET timer starts, press again: stops, press again: resumes.</human-check>
  </acceptance_criteria>
  <done>Full Phase 2 button UX is wired. All four requirements BTN-04/05/06/07 are active. Project builds and behaves correctly on hardware.</done>
</task>

</tasks>

<threat_model>
## Trust Boundaries

| Boundary | Description |
|---|---|
| ButtonHandler → main.cpp | isArmed(), startStopPressed(), stopResetPressed() return values; all hardware-sourced, already debounced by Bounce2 |
| main.cpp → TimerDisplay | setArmed(bool) call; value is boolean from ButtonHandler, no external input |
| main.cpp → emitTimerControl | All action string arguments are compile-time literals ("start", "stop", "reset") |

## STRIDE Threat Register

| Threat ID | Category | Component | Disposition | Mitigation Plan |
|---|---|---|---|---|
| T-02-04 | Tampering | timerDisplay.update() called before setArmed() | mitigate | loop() call order enforced: setArmed() immediately after poll(), update() after all button routing — wrong order would render one stale frame on arm transition |
| T-02-05 | Tampering | Blink state leak on disarm | mitigate | setArmed(false) resets _blink_state=true on disarm transition — display resumes visible immediately (Pitfall 3) |
| T-02-06 | Denial of Service | Armed display permanently stuck if _armed never cleared | accept | _armed is only ever cleared by _b2.rose() inside ButtonHandler::poll(); physical button release is the only path — no software path to get stuck |
| T-02-SC | Tampering | npm/pip/cargo installs | accept | No new packages; platformio.ini unchanged |
</threat_model>

<verification>
After both tasks complete:
- `pio run` exits 0
- `grep -c "setArmed" include/TimerDisplay.h` returns 1
- `grep -c "setArmed" src/TimerDisplay.cpp` returns at minimum 1 (definition)
- `grep -c "emitTimerControl" src/main.cpp` returns at minimum 3 (stop+reset in chord block, plus start or stop in toggle block)
- `grep -c "setArmed(buttonHandler.isArmed())" src/main.cpp` returns 1
- Phase 2 success criteria from ROADMAP.md verified:
  1. Button 1 alone toggles running/stopped and never resets
  2. Button 2 held ≥400ms shows yellow blinking "STOP?"; releasing disarms with no state change
  3. Button 1 pressed while armed → stop and reset regardless of prior state
</verification>

<success_criteria>
All four Phase 2 requirements (BTN-04, BTN-05, BTN-06, BTN-07) are fully implemented and wired. The armed display overlay is functional. Button event routing through emitTimerControl() is complete. Project builds with `pio run` and the three ROADMAP success criteria for Phase 2 are met.
</success_criteria>

<output>
Create `.planning/phases/02-button-ux/02-02-SUMMARY.md` when done.
</output>

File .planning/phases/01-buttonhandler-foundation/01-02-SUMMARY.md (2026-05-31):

---
phase: 01-buttonhandler-foundation
plan: "02"
subsystem: firmware
tags: [rp2040, platformio, c++, gpio, bounce2, main.cpp]

# Dependency graph
requires:
  - phase: 01-buttonhandler-foundation plan 01
    provides: ButtonHandler class with begin()/poll() and Bounce2 lib_deps entry
provides:
  - ButtonHandler wired into src/main.cpp with #define pin constants, file-scope global, begin() in setup(), poll()-first in loop()
  - Successful pio run build producing firmware.uf2 (BTN-03 confirmed)
affects:
  - 02-buttonhandler-events (Phase 2 — event accessors built on top of this wiring)

# Tech tracking
tech-stack:
  added: []
  patterns:
    - buttonHandler.poll() is first call in loop() — ensures button events are never starved by WebServer::handleClient() blocking
    - Button pin constants grouped in HARDWARE PIN CONFIGURATION block with "do not change" comment
    - File-scope stack-allocated global — ButtonHandler buttonHandler(BTN_1, BTN_2) — no heap allocation

key-files:
  created: []
  modified:
    - src/main.cpp

key-decisions:
  - "buttonHandler.poll() placed as absolute first call in loop() per BTN-02 starvation-prevention requirement"
  - "Stack-allocated global at file scope — no `new`, no pointer — satisfies D-03 and 264KB SRAM constraint"
  - "Button Init added as section 2 in setup() (before Ethernet) so INPUT_PULLUP and debounce are active before any network blocking"

patterns-established:
  - "Pattern: poll()-first ordering — buttonHandler.poll() precedes timerDisplay.update() and WebServer::handleClient() to guarantee sub-loop latency"
  - "Pattern: pin constants in HARDWARE PIN CONFIGURATION block with explicit 'do not change' comment for hardware-locked assignments"

requirements-completed: [BTN-01, BTN-02]

# Metrics
duration: 5min
completed: 2026-05-30
---

# Phase 01 Plan 02: ButtonHandler main.cpp Wiring Summary

**ButtonHandler wired into src/main.cpp with GPIO14/GPIO15 #defines, file-scope global, begin() in setup() section 2, and poll()-first loop(); pio run exits 0 producing firmware.uf2**

## Performance

- **Duration:** ~5 min
- **Started:** 2026-05-30T05:22:00Z
- **Completed:** 2026-05-30T05:27:00Z
- **Tasks:** 2
- **Files modified:** 1

## Accomplishments
- Added `#include "ButtonHandler.h"` to project headers block alongside other project headers (BTN-01, D-01)
- Added `#define BTN_1 14` / `#define BTN_2 15` in HARDWARE PIN CONFIGURATION block with "V2 PCB — fixed, do not change" comment (D-07)
- Declared `ButtonHandler buttonHandler(BTN_1, BTN_2)` as stack-allocated file-scope global in GLOBAL OBJECTS block (D-03)
- Added `buttonHandler.begin()` as setup() section 2 (renumbered Ethernet→3, Network→4, WebSocket→5, Settings→6) (BTN-01)
- Placed `buttonHandler.poll()` as first statement in loop(), removed stale `// 2. Normal Timer Update` comment (BTN-02)
- `pio run` exits 0, firmware.uf2 produced at 232640 bytes / 22.3% flash (BTN-03)

## Task Commits

Each task was committed atomically:

1. **Task 1: Wire ButtonHandler into src/main.cpp (BTN-01, BTN-02, D-03, D-07)** - `df2583b` (feat)
2. **Task 2: Build verification — pio run exits 0 (BTN-03)** - no separate commit (verification-only, no file changes)

**Plan metadata:** (committed with SUMMARY)

## Files Created/Modified
- `src/main.cpp` - Added ButtonHandler.h include, BTN_1/BTN_2 pin defines, buttonHandler global, begin() in setup(), poll() first in loop()

## Decisions Made
- `buttonHandler.poll()` placed as absolute first call in loop() to satisfy BTN-02's starvation-prevention requirement — WebServer::handleClient() can block; polling first guarantees every loop() iteration sees fresh button state before any blocking call
- Stack-allocated global `ButtonHandler buttonHandler(BTN_1, BTN_2)` at file scope (no `new`) — consistent with D-03 and the 264KB SRAM constraint; global lifetime avoids dangling-pointer risk
- Button Init inserted as setup() section 2, before Ethernet Hardware Init (section 3) — INPUT_PULLUP and 25ms debounce are armed before any network blocking code runs, eliminating T-01-03 floating GPIO window

## Deviations from Plan

None - plan executed exactly as written.

## Issues Encountered

None. All four changes applied cleanly. Build succeeded first attempt with no compiler errors or warnings related to ButtonHandler or Bounce2.

## User Setup Required

None - no external service configuration required.

## Next Phase Readiness
- Phase 1 is fully complete: BTN-01 (begin() in setup()), BTN-02 (poll() first in loop()), BTN-03 (Bounce2 in lib_deps, pio run exits 0) all satisfied
- Phase 2 (02-buttonhandler-events) can now add event accessor methods (button1Fell(), button2Held(), chord detection) on top of the wired ButtonHandler foundation
- Hardware bring-up verification: flash firmware.uf2 to RP2040, open serial monitor at 115200 baud, press each button — DEBUG_BUTTONHANDLER output should show "B1 fell" / "B2 fell" on clean LOW transitions with no phantom events at boot

## Self-Check

- [x] `#include "ButtonHandler.h"` in src/main.cpp — grep count: 1
- [x] `BTN_1 14` in src/main.cpp — grep count: 1
- [x] `BTN_2 15` in src/main.cpp — grep count: 1
- [x] `ButtonHandler buttonHandler(BTN_1, BTN_2)` in src/main.cpp — grep count: 1
- [x] `buttonHandler.begin()` in src/main.cpp — grep count: 1
- [x] `buttonHandler.poll()` in src/main.cpp — grep count: 1
- [x] `pio run` exits 0 with SUCCESS message — verified
- [x] `.pio/build/pico/firmware.uf2` exists (489472 bytes) — verified
- [x] Commit df2583b exists in git log — verified

## Self-Check: PASSED

---
*Phase: 01-buttonhandler-foundation*
*Completed: 2026-05-30*

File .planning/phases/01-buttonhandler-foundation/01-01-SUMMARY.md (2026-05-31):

---
phase: 01-buttonhandler-foundation
plan: "01"
subsystem: firmware
tags: [bounce2, debounce, gpio, rp2040, platformio, c++]

# Dependency graph
requires: []
provides:
  - ButtonHandler class with INPUT_PULLUP init and non-blocking Bounce2 polling on GPIO14/GPIO15
  - Bounce2 library declared in platformio.ini lib_deps
affects:
  - 01-02 (Phase 1 Plan 2 — main.cpp wiring of ButtonHandler)
  - 02-buttonhandler-events (Phase 2 — event accessors built on top of poll())

# Tech tracking
tech-stack:
  added:
    - thomasfredericks/Bounce2@^2.71 (PlatformIO registry, verified legitimate)
  patterns:
    - Constructor-injection: store pins in constructor, hardware init deferred to begin()
    - Debug macro flag: DEBUG_BUTTONHANDLER=true for Phase 1 serial verification
    - "#pragma once header guard (project convention, not #ifndef)"
    - 2-space indent with same-line opening brace

key-files:
  created:
    - include/ButtonHandler.h
    - src/ButtonHandler.cpp
  modified:
    - platformio.ini

key-decisions:
  - "Used attach(pin, INPUT_PULLUP) one-call form — no separate pinMode() per Bounce2 recommendation"
  - "DEBUG_BUTTONHANDLER set true so Phase 1 hardware bring-up can verify clean LOW transitions via serial"
  - "Phase 1 exposes only begin()/poll() — no event accessors; Phase 2 will add button1Fell() etc."

patterns-established:
  - "Pattern 1: ButtonHandler constructor stores only pin numbers — no hardware work before setup() runs"
  - "Pattern 2: poll() calls update() exactly once per Bounce instance per loop() invocation"
  - "Pattern 3: begin() uses Bounce.attach(pin, INPUT_PULLUP) + interval(25) for both buttons"

requirements-completed: [BTN-01, BTN-02, BTN-03]

# Metrics
duration: 2min
completed: 2026-05-31
---

# Phase 01 Plan 01: ButtonHandler Foundation Summary

**Bounce2-backed ButtonHandler class wrapping GPIO14/GPIO15 with INPUT_PULLUP init and 25ms non-blocking debounce, plus Bounce2 library declared in platformio.ini**

## Performance

- **Duration:** ~2 min
- **Started:** 2026-05-31T05:16:05Z
- **Completed:** 2026-05-31T05:17:24Z
- **Tasks:** 3
- **Files modified:** 3

## Accomplishments
- Declared `thomasfredericks/Bounce2@^2.71` in platformio.ini lib_deps, satisfying BTN-03
- Created `include/ButtonHandler.h` with #pragma once, constructor, begin(), poll() declarations and Bounce private members (BTN-01, D-04)
- Created `src/ButtonHandler.cpp` implementing constructor with member initializer list, begin() with attach(pin, INPUT_PULLUP)+interval(25) for both pins, poll() with update() calls and DEBUG_BUTTONHANDLER-gated serial diagnostics (BTN-01, BTN-02, D-05, D-06)

## Task Commits

Each task was committed atomically:

1. **Task 1: Add Bounce2 to platformio.ini lib_deps** - `d303ae6` (chore)
2. **Task 2: Create include/ButtonHandler.h** - `dd4bdce` (feat)
3. **Task 3: Create src/ButtonHandler.cpp** - `dba3224` (feat)

**Plan metadata:** (committed with SUMMARY)

## Files Created/Modified
- `platformio.ini` - Added `thomasfredericks/Bounce2@^2.71` as last active lib_deps entry
- `include/ButtonHandler.h` - ButtonHandler class declaration with #pragma once, Bounce2 include, public constructor/begin/poll, private _pin1/_pin2/_b1/_b2
- `src/ButtonHandler.cpp` - ButtonHandler implementation: member initializer constructor, begin() with INPUT_PULLUP attach + 25ms interval, poll() with update() and debug fell() diagnostics

## Decisions Made
- Used `Bounce.attach(pin, INPUT_PULLUP)` one-call form rather than separate `pinMode()` + `attach()` — per Bounce2 official docs, the two-argument form sets INPUT_PULLUP mode internally; no separate pinMode needed
- Set `DEBUG_BUTTONHANDLER true` — matches WebServer.cpp and WebSocketClient.cpp production state; enables serial output during Phase 1 hardware bring-up for BTN-01 success criterion verification
- Phase 1 header exposes only three public methods (constructor, begin, poll) — no event accessors; Phase 2 extends the class for start/stop/chord detection

## Deviations from Plan

None - plan executed exactly as written.

## Issues Encountered

None.

## User Setup Required

None - no external service configuration required.

## Next Phase Readiness
- ButtonHandler scaffold is ready for Plan 01-02 (main.cpp wiring: include, global declaration, begin() call in setup(), poll() as first loop() call)
- Phase 2 will add event accessor methods (button1Fell(), button2Held(), chord detection) on top of this foundation
- Threat T-01-03 (floating GPIO phantom press) is mitigated: INPUT_PULLUP set via attach() before first read, 25ms debounce filters boot transients

## Self-Check

- [x] `platformio.ini` contains `thomasfredericks/Bounce2@^2.71` — verified (grep count: 1)
- [x] `include/ButtonHandler.h` exists with #pragma once, no #ifndef — verified
- [x] `src/ButtonHandler.cpp` exists — verified
- [x] `attach(_pin1, INPUT_PULLUP)` count: 1 — verified
- [x] `attach(_pin2, INPUT_PULLUP)` count: 1 — verified
- [x] `interval(25)` count: 2 — verified
- [x] `delay()` count: 0 — verified
- [x] Commits d303ae6, dd4bdce, dba3224 exist in git log

## Self-Check: PASSED

---
*Phase: 01-buttonhandler-foundation*
*Completed: 2026-05-31*

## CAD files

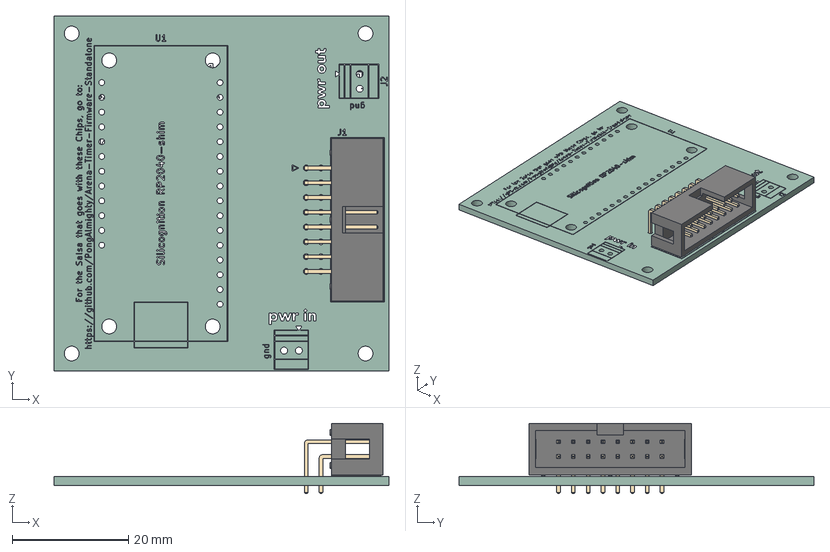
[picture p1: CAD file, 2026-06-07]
KiCad/ScoreboardPCBV2/ScoreboardPCB-Mini.step
57.5 x 61.0 x 12.1 mm
IDC-Header_2x08_P2.54mm_Horizontal
ScoreboardPCB-Mini_silkscreen x 2
ScoreboardPCB-Mini_PCB

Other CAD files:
V2gfx.dxf
v2.dwg

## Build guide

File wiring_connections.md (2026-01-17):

# Arena Timer PCB Wiring Specification

This document provides a complete guide for creating a PCB for the Arena Timer project. It includes a high-level project overview, a detailed hardware list, and the specific pin-to-pin wiring netlist needed to connect the RP2040 microcontroller to its peripherals.

## 1. Project Overview & Scope

The **Arena Timer** is a standalone, network-connected countdown timer designed for combat robotics matches (and similar timed events).

**Key Features:**
*   **High Visibility**: Uses a HUB75 RGB LED Matrix (managed by the `Adafruit_Protomatter` library) to display the match time and status messages.
*   **Network Control**: Connects via Ethernet to a local network. It runs a Web Server and WebSocket Client to allow remote control (Start/Stop/Reset) and status monitoring from a central "Fight Time" server or a web browser.
*   **Visual Feedback**: The display changes color based on configurable thresholds (e.g., Green -> Yellow -> Red) to visually warn drivers of time remaining.

## 2. Hardware Components

The system is designed to be compact, utilizing the RP2040-Shim to mount directly to the back of the matrix panel.

*   **Microcontroller**: **Silicognition RP2040-Shim**
    *   *Role*: Main controller. Handles all logic, drives the matrix directly via the PIO state machines, and manages the Ethernet stack.
    *   *Mounting*: Designed to solder directly to the HUB75 input header on the matrix.
    *   *Logic Voltage*: **3.3V** (NOT 5V tolerant).
*   **Display**: **HUB75 RGB LED Matrix Panel**
    *   *Type*: Standard HUB75 interface (e.g., 64x32 pixels, 1/16 scan).
    *   *Power*: Requires a separate high-current 5V power supply.
    *   *Logic*: Typically accepts 3.3V logic signals directly.
*   **Network**: **W5500 SPI Ethernet Module**
    *   *Configuration*: Wired to match the **Adafruit Ethernet FeatherWing** or **PoE FeatherWing** pinout.
    *   *Interface*: Uses the RP2040's **SPI1** peripheral.
    *   *Logic Voltage*: **3.3V** required.

## 3. Pin Connection Netlist

The following table maps the RP2040 GPIO pins to their respective peripheral connections. Use this for schematic routing.

> [!CAUTION]
> **Logic Level Warning**: All RP2040 GPIO pins are **3.3V Logic**. Do not connect 5V logic signals directly to the RP2040. The HUB75 Matrix is powered by 5V, but accepts 3.3V control signals.

| RP2040 GPIO | Function | IDC Pin | Peripheral Label | Notes |
| :--- | :--- | :--- | :--- | :--- |
| **GPIO 0** | Output (OE) | **15** | **TX** | Output Enable |
| **GPIO 1** | Output (LAT) | **14** | **RX** | Latch |
| **GPIO 6** | Output (R2) | **5** | **D4** | Red Data (Bottom) |
| **GPIO 10** | SPI1 SCK | - | **SCK** | Ethernet Clock |
| **GPIO 11** | SPI1 TX | - | **MOSI** | Ethernet MOSI |
| **GPIO 12** | SPI1 RX | - | **MISO** | Ethernet MISO |
| **GPIO 16** | Output (R1) | **1** | **SDA** | Red Data (Top) |
| **GPIO 17** | Output (G1) | **2** | **SCL** | Green Data (Top) |
| **GPIO 19** | Output (G2) | **6** | **D6** | Green Data (Bottom) |
| **GPIO 20** | Output (B1) | **3** | **D9** | Blue Data (Top) |
| **GPIO 21** | SPI1 CS | - | **D11** | Ethernet CS |
| **GPIO 22** | Output (CLK) | **13** | **D13** | Matrix Clock |
| **GPIO 25** | Output (B2) | **7** | **D25** | Blue Data (Bottom) |
| **GPIO 26** | Output (D) | **12** | **A3** | Address D |
| **GPIO 27** | Output (C) | **11** | **A2** | Address C |
| **GPIO 28** | Output (B) | **10** | **A1** | Address B |
| **GPIO 29** | Output (A) | **9** | **A0** | Address A |

### IDC Pin Sorted Netlist

| IDC Pin | Signal | RP2040 GPIO | Peripheral Label | Notes |
| :--- | :--- | :--- | :--- | :--- |
| **1** | **R1** | **GPIO 16** | **SDA** | Red Data (Top) |
| **2** | **G1** | **GPIO 17** | **SCL** | Green Data (Top) |
| **3** | **B1** | **GPIO 20** | **D9** | Blue Data (Top) |
| **4** | **GND** | - | **GND** | Ground |
| **5** | **R2** | **GPIO 6** | **D4** | Red Data (Bottom) |
| **6** | **G2** | **GPIO 19** | **D6** | Green Data (Bottom) |
| **7** | **B2** | **GPIO 25** | **D25** | Blue Data (Bottom) |
| **8** | **GND** | - | **GND** | Ground |
| **9** | **A** | **GPIO 29** | **A0** | Address A |
| **10** | **B** | **GPIO 28** | **A1** | Address B |
| **11** | **C** | **GPIO 27** | **A2** | Address C |
| **12** | **D** | **GPIO 26** | **A3** | Address D |
| **13** | **CLK** | **GPIO 22** | **D13** | Matrix Clock |
| **14** | **LAT** | **GPIO 1** | **RX** | Latch |
| **15** | **OE** | **GPIO 0** | **TX** | Output Enable |
| **16** | **GND** | - | **GND** | Ground |

*   **5V IN**: Connects from Matrix Power Supply 5V to **RP2040 VUSB Pin** (3rd pin on Right Header).
    > [!WARNING]
    > **Back-Powering Risk**: The VUSB pin connects directly to the USB 5V rail. **DO NOT** connect a standard USB cable to a computer while the external 5V supply is on. This will back-power your computer and could cause damage. Use a **data-only USB cable** (V+ cut) or disconnect external power before USB programming. Since this board has no BAT pin, there is no "safe" downstream injection point—you must manage this risk.
*   **3.3V OUT**: The RP2040-Shim takes 5V from VUSB and regulates it to 3.3V. This 3.3V rail powers the RP2040 and the W5500 Ethernet module.
*   **GND**: Common ground for ALL components.

## 4. Visual Wiring Diagram

```mermaid
graph TD
    subgraph RP2040 [RP2040-Shim Controller]
        GPIO0[GPIO 0]
        GPIO1[GPIO 1]
        GPIO6[GPIO 6]
        GPIO10[GPIO 10]
        GPIO11[GPIO 11]
        GPIO12[GPIO 12]
        GPIO16[GPIO 16]
        GPIO17[GPIO 17]
        GPIO19[GPIO 19]
        GPIO20[GPIO 20]
        GPIO21[GPIO 21]
        GPIO22[GPIO 22]
        GPIO25[GPIO 25]
        GPIO26[GPIO 26]
        GPIO27[GPIO 27]
        GPIO28[GPIO 28]
        GPIO29[GPIO 29]
    end

    subgraph Matrix [HUB75 RGB Matrix]
        OE
        LAT
        CLK
        R1
        G1
        B1
        R2
        G2
        B2
        ADDR_A
        ADDR_B
        ADDR_C
        ADDR_D
    end

    subgraph Ethernet [W5500 Ethernet SPI]
        SCK
        MOSI
        MISO
        CS
    end

    %% Matrix Connections
    GPIO0 --> OE
    GPIO1 --> LAT
    GPIO22 --> CLK
    GPIO16 --> R1
    GPIO17 --> G1
    GPIO20 --> B1
    GPIO6 --> R2
    GPIO19 --> G2
    GPIO25 --> B2
    GPIO29 --> ADDR_A
    GPIO28 --> ADDR_B
    GPIO27 --> ADDR_C
    GPIO26 --> ADDR_D

    %% Ethernet Connections
    GPIO10 --> SCK
    GPIO11 --> MOSI
    GPIO12 --> MISO
    GPIO21 --> CS
```

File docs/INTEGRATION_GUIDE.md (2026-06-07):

# Arena Timer Integration Guide

A complete technical reference for writing programs that interface with Arena Timer.

---

## 1. Integration Model

Arena Timer supports three control paths:

1. **HTTP REST API (direct control)** — your app sends HTTP requests to the timer device.
2. **Incoming Socket.IO feed (FightTimer-style)** — Arena Timer acts as a Socket.IO *client* and connects out to your server, then consumes `timer_update` messages.
3. **Outgoing Socket.IO events (physical buttons)** — Arena Timer emits `timer_control` events *to* your server when a physical button is pressed. Your server should handle these to keep all connected clients in sync.

---

## 2. Device Discovery and Connection

| Method | Value |
|---|---|
| mDNS | `http://arenatimer.local` |
| Static IP | `10.0.0.21` (fallback if DHCP fails) |
| HTTP port | `80` |

**Recommended discovery sequence:**
1. Try `arenatimer.local` via mDNS
2. Fall back to the configured or static IP
3. Perform a health check: `GET /api/network/status`

---

## 3. REST API Reference

### Base URL
```
http://<timer-host>
```

---

### `POST /api` — Timer commands

**Request body** (form-encoded):

| Field | Values |
|---|---|
| `action` | `start` · `pause` · `reset` · `flip` |

**Response** (JSON):
```json
{"status": "success", "message": "Timer started"}
```

**Error response:**
```json
{"status": "error", "message": "Unknown action: <value>"}
```

---

### `POST /api/settings` — Apply timer and display configuration

**Request body** (form-encoded):

| Field | Type | Description |
|---|---|---|
| `duration` | int | Duration in seconds (e.g. `180` = 3 minutes) |
| `font` | int | Font ID (see [Font ID table](#font-id-table)) |
| `spacing` | int | Extra pixels between characters |
| `brightness` | int | Display brightness `0–255` |
| `thresholds` | string | Pipe-delimited `seconds:#RRGGBB` pairs (URL-encoded) |
| `default` | string | Default color as `#RRGGBB` (URL-encoded) |

**Threshold format example** (before URL encoding):
```
120:#FFFF00|60:#FF0000
```
(meaning: yellow at ≤2 minutes, red at ≤1 minute)

**Full example curl:**
```bash
curl -X POST http://arenatimer.local/api/settings \
  -d "duration=180&font=4&spacing=3&brightness=255&thresholds=120:%23FFFF00%7C60:%23FF0000&default=%2300FF00"
```

**Response:**
- `200 OK` — body: `Settings saved`
- `500` — body: `Error saving settings`

---

### `GET /api/status` — Timer state

**Response:**
```json
{"isPaused": true}
```

| Field | Type | Description |
|---|---|---|
| `isPaused` | boolean | `true` if stopped after being started |

---

### `GET /api/settings` — Current configuration

**Response:**
```json
{"fontId": 4, "spacing": 3, "brightness": 255, "duration": 180}
```

| Field | Type | Description |
|---|---|---|
| `fontId` | int  | Active font (see table) |
| `spacing` | int  | Letter spacing (pixels) |
| `brightness` | int  | Brightness `0–255` |
| `duration` | int  | Total duration (seconds)|

---

### `GET /api/thresholds` — Color thresholds

**Response:**
```json
{
  "thresholds": [
    {"seconds": 120, "color": "#FFFF00"},
    {"seconds": 60,  "color": "#FF0000"}
  ],
  "defaultColor": "#00FF00"
}
```

Thresholds are returned in descending order by `seconds`. The timer uses the color of the lowest threshold whose `seconds` value is ≥ the current remaining time. If no threshold matches, `defaultColor` is used.

---

### `GET /api/network/status` — Network info

**Response:**
```json
{"ip": "10.0.0.21"}
```

---

### WebSocket Connection Management

#### `POST /api/websocket/connect`

**Request body** (form-encoded):

| Field  | Default | Description |
|---|---|---|
| `host` | *(required)*  | IP or hostname of your WS server  |
| `port` | `8765` | Port number |
| `path` | `/socket.io/` | WebSocket path |
| `ns` | `/` | Socket.IO namespace |

**Namespace format (FightTimer):** Use `/timer1` through `/timer5` — e.g. `ns=/timer1`. Do **not** use `/timer/1` (slash-separated format is not supported).

**Response:**
```json
{"status": "success", "message": "Connecting..."}
```

The connection completes asynchronously. Poll `/api/websocket/status` to confirm.

---

#### `POST /api/websocket/disconnect`

No body required.

**Response:**
```json
{"status": "success", "message": "Disconnected"}
```

---

#### `GET /api/websocket/status`

**Response:**
```json
{"connected": true, "url": "ws://192.168.1.100:8765/socket.io/"}
```

---

## 4. Socket.IO Message Contract (Server → Timer)

Once Arena Timer connects to your Socket.IO endpoint, it parses incoming messages in any of the following forms:

### Form 1 — Socket.IO event array (standard)
```json
["timer_update", {"action": "start"}]
```
Sent as packet `42[...]` in Socket.IO EIO4 framing.

### Form 2 — Wrapped object
```json
{"timer_update": {"action": "reset", "minutes": 3, "seconds": 0}}
```

### Form 3 — Flat action object
```json
{"action": "stop"}
```

---

### Supported `action` values

| Action | Fields | Behavior |
|---|---|---|
| `start` | `is_heartbeat` (bool, optional) | Starts or resumes the timer. Ignored if `is_heartbeat` is `true`. |
| `stop` | *(none)* | Pauses the timer |
| `reset` | `minutes` (int), `seconds` (int), `is_initial_sync` (bool, optional) | Sets duration and resets timer to idle. Defaults: `minutes=3`, `seconds=0`. If `is_initial_sync` is `true`, the next `start` event is treated as the initial sync and skips any round-trip status request. |
| `settings` | `settings` (object) | Acknowledged but not currently applied to physical timer |

---

### `timer_status` event (initial sync)

On initial connect, if the server sends a `timer_status` event, the timer will apply the authoritative server time:

```json
["timer_status", {"time_left": 180}]
```

| Field | Type | Description |
|---|---|---|
| `time_left` | int  | Remaining time in seconds |

The timer will set its duration, reset, and start immediately from `time_left`.

---

### Socket.IO handshake sequence

Arena Timer handles the Socket.IO EIO4 protocol directly over a plain WebSocket connection. The handshake your server will observe:

1. **Client → Server**: HTTP upgrade to `ws://<host>:<port>/socket.io/?EIO=4&transport=websocket`
2. **Server → Client**: `0{...}` (EIO OPEN packet with session info)
3. **Client → Server**: `40` or `40<namespace>,` (Socket.IO CONNECT to namespace)
4. **Server → Client**: `40` (CONNECT acknowledged)
5. **Keepalive**: Server sends `2` (PING); timer replies with `3` (PONG)

---

## 5. Socket.IO Message Contract (Timer → Server)

When a physical button triggers a timer action, Arena Timer emits a `timer_control` event to your server **before** applying the action locally.

### Event format
```json
["timer_control", {"action": "start|stop|reset"}]
```

Sent as a standard Socket.IO `42[...]` packet on the configured namespace.

### Supported actions emitted

| Action  | Trigger |
|---|---|
| `start` | Button 1 pressed while timer is stopped  |
| `stop`  | Button 1 pressed while timer is running  |
| `reset` | Button 1 pressed while Button 2 is held  |

**Important — echo suppression:** After emitting `timer_control`, the timer opens a 500ms suppression window for that action. If the server echoes the same action back as a `timer_update` within that window, the timer ignores it (prevents double-actuation). The window is one-shot and action-matched.

Your server should treat `timer_control` the same as any other client requesting a timer action — apply it and broadcast the resulting `timer_update` to all connected clients as usual.

---

## 6. Physical Button Behavior

Arena Timer has two buttons wired to the V2 PCB:

| Button | GPIO | Role |
|---|---|---|
| Button 1 | 14 | Start / Stop (primary) |
| Button 2 | 15 | Arm modifier (hold to arm)  |

### State machine

```
DISARMED (default)
  Button 1 pressed → emit timer_control("start") or timer_control("stop")
                     (toggles based on current run state)
  Button 2 held ≥400ms → enter ARMED state (display shows overlay)

ARMED (Button 2 held)
  Button 1 pressed → emit timer_control("stop") + timer_control("reset")
                     (chord: stop-and-reset)
  Button 2 released → return to DISARMED
```

The armed state shows a visual confirmation overlay on the display. A hold-to-confirm interaction prevents accidental resets during a match.

---

## 7. Recommended Client Workflow

### Direct REST control
```
1. Discover host (mDNS or static IP)
2. GET /api/settings          → read current config
3. GET /api/thresholds         → read current thresholds
4. POST /api/settings          → push desired config
5. POST /api     action=start  → start the timer
   POST /api     action=pause  → pause the timer
   POST /api     action=reset  → reset the timer
6. GET /api/status             → poll timer state
```

### FightTimer / Socket.IO integration
```
1. Arena Timer calls POST /api/websocket/connect with your server's host/port/ns
2. Arena Timer connects and subscribes to timer_update events
3. Your server sends timer_update events to control the timer
4. Your server receives timer_control events when physical buttons are pressed
5. Treat timer_control events like any client action — broadcast to all clients
```

---

## 8. Font ID Table

| ID | Font |
|----|---|
| 0  | Default (5×7 pixel, 2×) |
| 1  | FreeSans 9pt |
| 2  | FreeSans 12pt |
| 3  | FreeSansBold 9pt |
| 4  | **FreeSansBold 12pt** *(default)* |
| 5  | FreeMono 9pt |
| 6  | FreeMono 12pt |
| 7  | FreeMonoBold 9pt |
| 8  | FreeMonoBold 12pt |
| 9  | FreeSerif 9pt |
| 10 | FreeSerif 12pt |
| 11 | FreeSerifBold 9pt |
| 12 | FreeSerifBold 12pt |
| 13 | Org_01 (retro pixel, 3×) |
| 14 | Picopixel (retro pixel, 3×)|
| 15 | TomThumb (retro pixel, 3×) |
| 16 | Aquire Regular 12pt |
| 17 | AquireBold 12pt |
| 18 | AquireLight 12pt |

---

## 9. Reliability Notes

- **No authentication or TLS** is implemented in the firmware. Deploy on a trusted LAN or VLAN.
- Use **retry with backoff** for HTTP calls.
- Timer commands are idempotent at the device level (safe to resend).
- **Validate** state after each command with a follow-up `GET /api/status`.
- Connection settings (host, port, path, namespace) are persisted to EEPROM and restored on reboot. The timer will auto-reconnect on boot if a prior connection was configured.
- Auto-reconnect uses **exponential backoff**: 10s → 20s → 40s → 60s (capped), resetting on successful connection.
- **Namespace validation:** On boot, the timer validates the stored namespace against the allowed set (`/`, `/timer1`–`/timer5`). Malformed values are reset to `/` and re-saved automatically.

---

## 10. Quick Reference — cURL Cheatsheet

```bash
# Start timer
curl -X POST http://arenatimer.local/api -d "action=start"

# Pause timer
curl -X POST http://arenatimer.local/api -d "action=pause"

# Reset timer
curl -X POST http://arenatimer.local/api -d "action=reset"

# Flip display orientation
curl -X POST http://arenatimer.local/api -d "action=flip"

# Set 3-minute duration with yellow/red thresholds
curl -X POST http://arenatimer.local/api/settings \
  -d "duration=180&font=4&spacing=3&brightness=255&thresholds=120:%23FFFF00%7C60:%23FF0000&default=%2300FF00"

# Get timer status
curl http://arenatimer.local/api/status

# Get current settings
curl http://arenatimer.local/api/settings

# Get color thresholds
curl http://arenatimer.local/api/thresholds

# Get IP address
curl http://arenatimer.local/api/network/status

# Connect Arena Timer's Socket.IO client to a FightTimer server (timer slot 1)
curl -X POST http://arenatimer.local/api/websocket/connect \
  -d "host=192.168.1.100&port=8765&path=/socket.io/&ns=/timer1"

# Check WebSocket connection status
curl http://arenatimer.local/api/websocket/status

# Disconnect WebSocket
curl -X POST http://arenatimer.local/api/websocket/disconnect
```

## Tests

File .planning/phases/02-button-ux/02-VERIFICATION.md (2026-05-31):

---
phase: 02-button-ux
verified: 2026-05-31T00:00:00Z
status: human_needed
score: 11/11 must-haves verified
overrides_applied: 0
human_verification:
  - test: "Hold Button 2 for >= 400ms — confirm yellow 'STOP?' blinks on matrix. Release Button 2 without pressing Button 1 — confirm display returns to normal timer with no timer state change (time not reset, running state unchanged)."
    expected: "Yellow 'STOP?' blinks on matrix while Button 2 is held. On release, matrix returns to normal timer display. Timer state is identical before and after the hold-release cycle."
    why_human: "Requires physical hardware — GPIO input, Bounce2 timing, LED matrix output, and 400ms hold timing cannot be verified programmatically."
  - test: "While Button 2 is held (armed), press Button 1 — confirm timer stops and resets to RESET state regardless of whether it was RUNNING or STOPPED before the chord."
    expected: "Timer returns to RESET state. Matrix returns to normal timer display. Both RUNNING→RESET and STOPPED→RESET chord paths must be confirmed."
    why_human: "Requires physical hardware execution and observation of timer state transitions through the matrix display."
  - test: "Press Button 1 alone (no Button 2 held) in sequence: RESET → press → running clock. Press again → stopped (time preserved). Press again → resumes from where it stopped. Confirm Button 1 alone never resets the timer."
    expected: "First press: timer starts counting down. Second press: timer freezes at stopped time. Third press: timer resumes from frozen time. No reset occurs on any solo Button 1 press."
    why_human: "Toggle behavior and absence-of-reset require visual confirmation on hardware. isRunning()/isRunning() state transitions cannot be trace-verified without live execution."
---

# Phase 2: Button UX Verification Report

**Phase Goal:** A box ref can start, stop, and arm-then-reset the timer using the two physical buttons
**Verified:** 2026-05-31
**Status:** human_needed
**Re-verification:** No — initial verification

## Goal Achievement

### Observable Truths

| # | Truth | Status | Evidence |
|---|---|---|---|
| 1 | ButtonHandler exposes isArmed() (persistent), startStopPressed() (one-shot), stopResetPressed() (one-shot) | VERIFIED | `include/ButtonHandler.h` lines 23-30: all three public declarations with correct signatures and doxygen comments |
| 2 | Armed state is entered when Button 2 has been held LOW for >=400ms and is still held | VERIFIED | `src/ButtonHandler.cpp` line 38: `if (_b2.read() == LOW && _b2.currentDuration() >= 400) { _armed = true; }` |
| 3 | Armed state is cleared when Button 2 rises (_b2.rose()); releasing Button 2 alone causes no timer action | VERIFIED | `src/ButtonHandler.cpp` line 43-45: `if (_b2.rose()) { _armed = false; }` — no timer call on this path |
| 4 | Button 1 fell while disarmed sets _startStopPending=true; while armed sets _stopResetPending=true | VERIFIED | `src/ButtonHandler.cpp` lines 48-56: correct branching inside `if (_b1.fell())` after armed state is settled |
| 5 | One-shot flags are reset to false at the top of every poll() call before any evaluation | VERIFIED | `src/ButtonHandler.cpp` lines 33-34: `_startStopPending = false; _stopResetPending = false;` before all conditionals |
| 6 | Arm check evaluates before Button 1 routing inside poll() | VERIFIED | `src/ButtonHandler.cpp`: arm detection at lines 37-40, disarm at 43-45, B1 routing at 48-56 — order confirmed |
| 7 | Phase 1 BTN1/BTN2 fell diagnostics are removed from poll() | VERIFIED | `grep "BTN1 fell\|BTN2 fell" src/ButtonHandler.cpp` returns empty — Phase 1 strings absent |
| 8 | WebSocketClient declares and implements emitTimerControl(const char* action) | VERIFIED | `include/WebSocketClient.h` line 28: declaration present; `src/WebSocketClient.cpp` lines 477-488: implementation present |
| 9 | emitTimerControl dispatches to _timer->start() / _timer->stop() / _timer->reset() via strcmp | VERIFIED | `src/WebSocketClient.cpp` lines 478-487: three strcmp branches each calling the correct _timer method |
| 10 | TimerDisplay setArmed(bool) implemented with blink-state reset on both arm and disarm transitions; armed update() short-circuits to yellow STOP? at 1Hz | VERIFIED | `src/TimerDisplay.cpp` lines 218-250: setArmed() resets _blink_state=true on both transitions; update() if(_armed) block with color565(255,200,0), setCursor(17,12), print("STOP?"), return |
| 11 | main.cpp loop() wires setArmed, stopResetPressed, startStopPressed routing, correct call order, null guards | VERIFIED | `src/main.cpp` lines 131-157: poll→setArmed→stopResetPressed(stop+reset)→startStopPressed(toggle)→update→Ethernet.maintain→handleClient→wsClient->poll; all emitTimerControl calls inside if(wsClient) |

**Score:** 11/11 truths verified

### Required Artifacts

| Artifact | Expected | Status | Details |
|---|---|---|---|
| `include/ButtonHandler.h` | Armed state machine API: isArmed(), startStopPressed(), stopResetPressed() | VERIFIED | All three public accessors declared (line 23-30); private members _armed, _startStopPending, _stopResetPending at lines 37-39 |
| `src/ButtonHandler.cpp` | Armed state machine implementation with _b2.currentDuration() >= 400 | VERIFIED | Full state machine in poll() (lines 28-64); arm threshold at line 38; accessors as one-liners at lines 62-64 |
| `include/WebSocketClient.h` | emitTimerControl declaration | VERIFIED | Line 28: `void emitTimerControl(const char* action);` under Phase 2 comment |
| `src/WebSocketClient.cpp` | emitTimerControl with strcmp dispatch to _timer methods | VERIFIED | Lines 477-488: full implementation with start/stop/reset branches |
| `include/TimerDisplay.h` | setArmed(bool) declaration, _armed private member | VERIFIED | Lines 103-105: public setArmed declaration; line 143: `bool _armed;` in private section |
| `src/TimerDisplay.cpp` | setArmed() implementation + armed short-circuit in update() | VERIFIED | Lines 218-250: setArmed() with transition handling; update() armed block with color565(255,200,0), setCursor(17,12), print("STOP?"), return |
| `src/main.cpp` | Button event routing and armed display wiring in loop() | VERIFIED | Lines 131-157: complete wiring matching plan spec exactly |

### Key Link Verification

| From | To | Via | Status | Details |
|---|----|-----|---|---|
| `src/ButtonHandler.cpp poll()` | `_startStopPending / _stopResetPending flags` | bool flags set in poll(), read by accessors | VERIFIED | Lines 33-34 reset flags; lines 50,54 set them; lines 63-64 expose via const accessors |
| `src/WebSocketClient.cpp emitTimerControl()` | `_timer->start() / _timer->stop() / _timer->reset()` | strcmp dispatch on action string | VERIFIED | Lines 478,481,484: strcmp checks; lines 480,483,486: _timer method calls |
| `src/main.cpp loop()` | `timerDisplay.setArmed()` | buttonHandler.isArmed() return value | VERIFIED | Line 132: `timerDisplay.setArmed(buttonHandler.isArmed());` — exact pattern match |
| `src/TimerDisplay.cpp update()` | STOP? rendering block | `_armed` early-return guard | VERIFIED | Line 234: `if (_armed) {` opens block; line 249: `return;` exits before normal rendering |
| `src/main.cpp loop()` | `wsClient->emitTimerControl()` | startStopPressed() / stopResetPressed() one-shot flags | VERIFIED | Lines 134-148: four emitTimerControl calls, all inside if(wsClient) null guards |

### Data-Flow Trace (Level 4)

These artifacts render display output from hardware input rather than DB queries.

| Artifact | Data Variable | Source | Produces Real Data | Status |
|---|---|---|---|---|
| `src/TimerDisplay.cpp update()` | `_armed` | `setArmed(buttonHandler.isArmed())` in main.cpp loop | Yes — live GPIO state via Bounce2 poll | FLOWING |
| `src/main.cpp loop()` | `startStopPressed()` / `stopResetPressed()` | `ButtonHandler::poll()` Bounce2 edge detection | Yes — hardware falling-edge events | FLOWING |
| `src/WebSocketClient.cpp emitTimerControl()` | `action` string | compile-time literals from main.cpp callers | Yes — hardcoded literals, no empty paths | FLOWING |

### Behavioral Spot-Checks

This is an embedded firmware target (RP2040). No runnable CLI entry points exist for the target binary. Step 7b SKIPPED — no host-runnable entry points. Build verification substitutes:

| Behavior | Command | Result | Status |
|---|---|---|---|
| Project builds without errors | `pio run` | `[SUCCESS] Took 1.06 seconds` | PASS |
| Phase 1 diagnostics removed | `grep "BTN1 fell\|BTN2 fell" src/ButtonHandler.cpp` | empty | PASS |
| Accessor declarations present (3) | `grep -c "isArmed\|startStopPressed\|stopResetPressed" include/ButtonHandler.h` | 3 | PASS |
| emitTimerControl in header | `grep -c "emitTimerControl" include/WebSocketClient.h` | 1 | PASS |
| setArmed wired in main.cpp | `grep -c "setArmed(buttonHandler.isArmed())" src/main.cpp` | 1 | PASS |
| emitTimerControl calls in main.cpp | `grep -c "emitTimerControl" src/main.cpp` | 4 (stop+reset chord + stop/start toggle) | PASS |

### Requirements Coverage

| Requirement | Source Plan | Description | Status | Evidence |
|---|---|---|---|---|
| BTN-04 | 02-01, 02-02 | Button 1 solo press toggles running/stopped only; never resets | VERIFIED (automated) / NEEDS HUMAN (behavioral) | startStopPressed() routes to emitTimerControl("start") or emitTimerControl("stop") via isRunning() toggle in main.cpp; hardware confirmation deferred to human check |
| BTN-05 | 02-01, 02-02 | Button 2 held >=400ms enters armed; release disarms with no action | VERIFIED (automated) / NEEDS HUMAN (behavioral) | _b2.currentDuration()>=400 sets _armed; _b2.rose() clears it; no timer call on disarm path |
| BTN-06 | 02-01, 02-02 | Button 1 while armed → stop and reset | VERIFIED (automated) / NEEDS HUMAN (behavioral) | stopResetPressed() routes to emitTimerControl("stop") then emitTimerControl("reset") in main.cpp |
| BTN-07 | 02-02 | Armed display overrides to yellow "STOP?" blinking at 1Hz | VERIFIED (automated) / NEEDS HUMAN (visual) | color565(255,200,0), setCursor(17,12), print("STOP?"), 500ms blink toggle in TimerDisplay::update() armed block |

### Anti-Patterns Found

| File | Line | Pattern | Severity | Impact |
|---|---|---|---|---|
| None found | — | — | — | — |

No TBD, FIXME, XXX, placeholder strings, empty return stubs, or hardcoded empty data found in any of the four modified files.

### Human Verification Required

The automated code analysis confirms all implementation is present and wired correctly. The following hardware behaviors require physical verification on the V2 PCB:

#### 1. Armed display overlay (BTN-05, BTN-07)

**Test:** Hold Button 2 (GPIO15) for >= 400ms. Observe the 64x32 RGB matrix.
**Expected:** Yellow text "STOP?" appears and blinks at approximately 1Hz (500ms on / 500ms off). Release Button 2 without pressing Button 1. Expected: matrix immediately returns to the normal timer countdown display with no change to the running/stopped state or the displayed time.
**Why human:** Requires physical hardware — GPIO active-low, Bounce2 timing, LED matrix output, and the 400ms threshold cannot be simulated in a host build.

#### 2. Chord reset (BTN-06)

**Test:** With the timer running, hold Button 2 for >= 400ms (confirm STOP? appears), then press Button 1 while still holding Button 2.
**Expected:** Timer stops and resets to the configured duration (RESET state). Matrix returns to normal display. Repeat with timer stopped (not running) — same result expected.
**Why human:** Two-state coverage (RUNNING→RESET and STOPPED→RESET) requires hardware execution and visual confirmation of timer state.

#### 3. Start/stop toggle, no-reset guarantee (BTN-04)

**Test:** With timer in RESET state, press Button 1 alone. Press again. Press again. Press five or more times.
**Expected:** First press: timer starts counting down (RUNNING). Second press: timer freezes (STOPPED, time preserved). Third press: timer resumes (RUNNING from where it stopped). No press of Button 1 alone causes a reset — the displayed time never jumps back to the full configured duration.
**Why human:** Toggle logic and the negative assertion (never resets) require live observation. isRunning() branch logic is code-verified but the actual timer state machine behavior needs hardware confirmation.

### Gaps Summary

No automated gaps found. All 11 must-have truths are verified in the codebase. All four requirements (BTN-04/05/06/07) have complete implementations wired end-to-end. The three items in Human Verification Required above represent planned hardware confirmation deferred from the 02-02-PLAN.md task 2 human-check block — they are not defects found during verification.

---

_Verified: 2026-05-31_
_Verifier: Claude (gsd-verifier)_

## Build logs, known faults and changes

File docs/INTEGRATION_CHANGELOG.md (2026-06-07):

# Arena Timer Integration — What's New

This document calls out the additions and corrections to the integration spec since the original guide was distributed. If you built against the earlier version, here's what to look for.

---

## 1. The Timer Now Talks Back — `timer_control` Events

**This is the biggest addition.** When a physical button on the timer is pressed, Arena Timer now emits a `timer_control` event to your Socket.IO server *before* applying the action locally.

```json
["timer_control", {"action": "start"}]
// or "stop" or "reset"
```

**What this means for your server:** You need to listen for `timer_control` events on each timer's namespace. Treat them the same as any other client requesting an action — apply the action and broadcast a `timer_update` to all connected clients as usual.

If your server doesn't handle `timer_control`, physical button presses will still work locally on the timer, but your other connected clients won't be notified.

---

## 2. Physical Buttons Exist

The original guide had no mention of hardware buttons. The V2 PCB has two:

| Button | GPIO | Normal press | Hold Button 2 first, then press Button 1 |
|---|---|---|---|
| Button 1 | 14 | Start / Stop toggle | Stop + Reset (chord) |
| Button 2 | 15 | Hold ≥400ms to arm | — |

The display shows a visual overlay when Button 2 is held (armed state) to confirm the chord before committing.

---

## 3. Echo Suppression — Don't Double-Send

After the timer emits `timer_control`, it opens a **500ms suppression window** for that action. If your server echoes the same action back as a `timer_update` within that window, the timer ignores it.

This is automatic and you don't need to implement anything special — but it's worth knowing so you don't mistake a "missing" response for a bug. The timer already acted on the button press locally; the echo just gets dropped.

---

## 4. Namespace Format Correction

The earlier guide showed `/` as the default namespace, which is correct for a generic connection. However, if you're using FightTimer-style multi-timer routing, the correct namespace format is:

```
/timer1   /timer2   /timer3   /timer4   /timer5
```

**Not** `/timer/1` (slash-separated). The firmware validates stored namespaces on boot and rejects that format.

When calling `POST /api/websocket/connect`, pass `ns=/timer1` (or whichever slot).

---

## 5. New Socket.IO Events (Server → Timer)

Two event fields were not documented in the original guide:

### `is_heartbeat` on `start` events
If your server broadcasts periodic heartbeat `start` events to keep clients in sync, set `is_heartbeat: true`. The timer ignores these, preventing unintended restarts from background broadcasts.

```json
["timer_update", {"action": "start", "is_heartbeat": true}]
```

### `is_initial_sync` on `reset` events
When a timer first connects mid-match, send a `reset` with `is_initial_sync: true` followed by a `start`. This tells the timer the next `start` is the initial sync and skips an internal round-trip status request.

```json
["timer_update", {"action": "reset", "minutes": 2, "seconds": 30, "is_initial_sync": true}]
["timer_update", {"action": "start"}]
```

### `timer_status` event (authoritative sync)
If you emit a `timer_status` event, the timer will immediately apply the server's authoritative time:

```json
["timer_status", {"time_left": 150}]
```

The timer will set its duration to `time_left` seconds, reset, and start.

---

## 6. EEPROM Persistence & Auto-Reconnect

Connection settings (host, port, path, namespace) are saved to EEPROM on first connect and restored automatically on reboot. The timer will attempt to reconnect using exponential backoff (10s → 20s → 40s → 60s max). You don't need to re-send the connect command after a power cycle.

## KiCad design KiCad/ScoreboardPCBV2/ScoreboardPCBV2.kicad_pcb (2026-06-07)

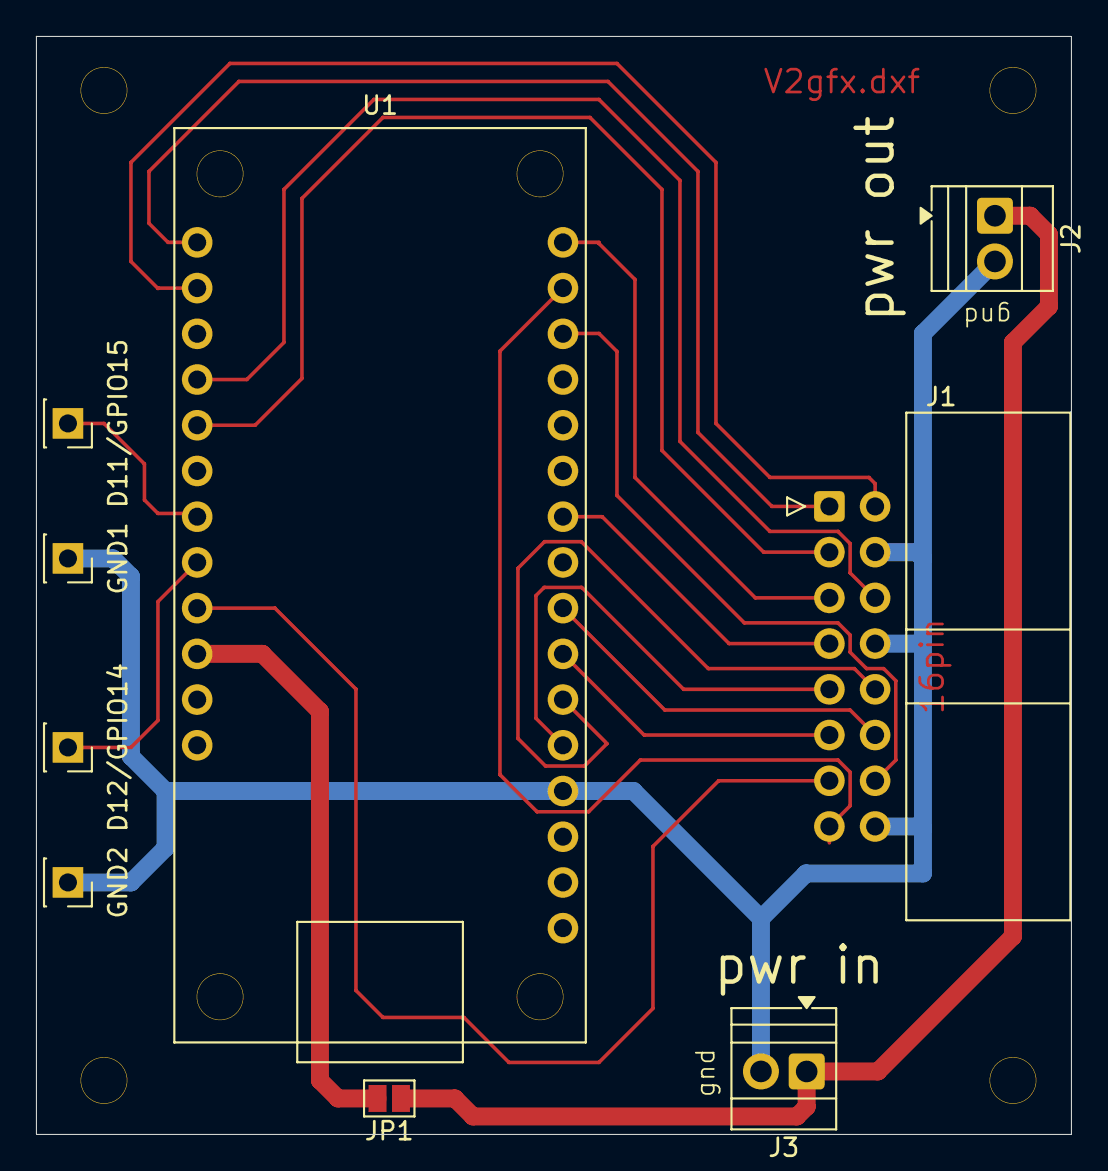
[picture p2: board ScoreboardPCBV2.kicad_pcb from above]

Board: 2 copper layers, 57.5 x 61.0 mm, 9 parts (0 on the bottom side), 18 nets.

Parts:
D11/GPIO15: D11/GPIO15; PinSocket_1x01_P2.54mm_Vertical
D12/GPIO14: D12/GPIO14; PinSocket_1x01_P2.54mm_Vertical
GND1, GND2: GND; PinSocket_1x01_P2.54mm_Vertical
J1: 10056844-116ALF; IDC-Header_2x08_P2.54mm_Horizontal
J2, J3: Screw_Terminal_01x02; TerminalBlock_Xinya_XY308-2.54-2P_1x02_P2.54mm_Horizontal
JP1: Bridge For POE Powah!; SolderJumper-2_P1.3mm_Open_Pad1.0x1.5mm
U1: RP2040-Shim; Adafruit-Feather-RP2040

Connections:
unnamed: J2.1, J3.1, JP1.1 (A)
unnamed: GND1.1, GND2.1, J1.4, J1.8, J1.16, J2.2, J3.2, U1.4 (GND)
unnamed: JP1.2 (B), U1.26 (VUSB)
unnamed: J1.9, U1.5 (A0/GPIO29)
unnamed: J1.10, U1.6 (A1/GPIO28)
unnamed: J1.11, U1.7 (A2/GPIO27)
unnamed: J1.12, U1.8 (A3/GPIO26)
unnamed: J1.5, U1.16 (D4/GPIO6)
unnamed: J1.6, U1.20 (D6/GPIO19)
unnamed: J1.3, U1.21 (D9/GPIO20)
unnamed: D11/GPIO15.1, U1.23 (D11/GPIO15)
unnamed: D12/GPIO14.1, U1.24 (D12/GPIO14)
unnamed: J1.13, U1.25 (D13/GPIO22)
unnamed: J1.7, U1.10 (D25/GPIO25)
unnamed: J1.14, U1.14 (RX/GPIO1)
unnamed: J1.2, U1.18 (SCL/GPIO17)
unnamed: J1.1, U1.17 (SDA/GPIO16)
unnamed: J1.15, U1.15 (TX/GPIO0)

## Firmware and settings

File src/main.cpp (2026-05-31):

#include "ButtonHandler.h"
#include "TimerDisplay.h"
#include "WebServer.h"
#include "WebSocketClient.h"
#include <Adafruit_Protomatter.h>
#include <Arduino.h>
#include <Ethernet_Generic.h>
#include <SPI.h>

// ----------------------------------------------------------------------------
// HARDWARE PIN CONFIGURATION (Verified)
// ----------------------------------------------------------------------------

// RGB Matrix Pins (RP2040-Shim / SPI0)
uint8_t rgbPins[] = {16, 17, 20, 6, 19, 25};
uint8_t addrPins[] = {29, 28, 27, 26};
uint8_t clockPin = 22;
uint8_t latchPin = 1;
uint8_t oePin = 0;

// Ethernet Pins (W5500 / SPI1)
#define ETH_SCK 10
#define ETH_TX 11
#define ETH_RX 12
#define ETH_CS 21

// Button Pins (V2 PCB — fixed, do not change)
#define BTN_1 14
#define BTN_2 15

// ----------------------------------------------------------------------------
// GLOBAL OBJECTS
// ----------------------------------------------------------------------------

Adafruit_Protomatter matrix(64, 4, 1, rgbPins, 4, addrPins, clockPin, latchPin,
                            oePin, true);

TimerDisplay timerDisplay(matrix);
ButtonHandler buttonHandler(BTN_1, BTN_2);
WebSocketClient *wsClient = nullptr;

// Network Config defaults
uint8_t mac[] = {0xDE, 0xAD, 0xBE, 0xEF, 0xFE, 0xED};
uint8_t ip[] = {10, 0, 0, 21}; // Fallback static IP
const char *hostname = "arenatimer";

// ----------------------------------------------------------------------------
// SETUP
// ----------------------------------------------------------------------------
void setup() {
  // Explicitly initialize GPIO 0 (OE) and GPIO 1 (LAT) as SIO outputs to override UART0 peripheral muxing
  gpio_init(0);
  gpio_set_dir(0, GPIO_OUT);
  gpio_init(1);
  gpio_set_dir(1, GPIO_OUT);

  Serial.begin(115200);
  Serial.println("\n=== Arena Timer Booting ===");

  // 1. Matrix Init
  ProtomatterStatus status = matrix.begin();
  Serial.print("Matrix Status: ");
  Serial.println((int)status);

  matrix.fillScreen(0);
  matrix.setCursor(0, 0);
  matrix.setTextColor(matrix.color565(0, 0, 255));
  matrix.println("Arena");
  matrix.println("Timer");
  matrix.show();

  // 2. Button Init
  buttonHandler.begin();

  // 3. Ethernet Hardware Init (SPI1)
  SPI1.setSCK(ETH_SCK);
  SPI1.setTX(ETH_TX);
  SPI1.setRX(ETH_RX);
  SPI1.begin();

  Ethernet.init(ETH_CS);

  // 4. Network Logic Init
  Serial.print("Initializing Network...");
  timerDisplay.showMessage("DHCP...");
  if (WebServer::init(mac, ip)) {
    Serial.println("OK");
    WebServer::startWebServer(80);
    WebServer::initMDNS(hostname);

    Serial.print("IP: ");
    Serial.println(Ethernet.localIP());
    timerDisplay.showMessage(String(Ethernet.localIP()[0]) + "." +
                             String(Ethernet.localIP()[1]) + "." +
                             String(Ethernet.localIP()[2]) + "." +
                             String(Ethernet.localIP()[3]));
    matrix.show();
    delay(2000);
  } else {
    Serial.println("FAIL");
    matrix.fillScreen(0);
    matrix.setTextColor(matrix.color565(255, 0, 0));
    matrix.println("Net Err");
    matrix.show();
  }

  // 5. WebSocket Init
  wsClient = new WebSocketClient(&timerDisplay.getTimer());
  WebServer::setWebSocketClient(wsClient);

  // 6. Load Persistent Settings
  Serial.print("Loading saved settings...");
  if (WebServer::loadSettings(timerDisplay)) {
    Serial.println("OK");
  } else {
    Serial.println("Using defaults");
    // Default initial setup if no settings exist
    timerDisplay.getTimer().setDuration(Timer::Components{3, 0, 0});
    timerDisplay.clearColorThresholds();
    timerDisplay.addColorThreshold(60, 255, 0, 0);
    timerDisplay.addColorThreshold(120, 255, 255, 0);
  }

  matrix.fillScreen(0);
}

// ----------------------------------------------------------------------------
// LOOP
// ----------------------------------------------------------------------------
void loop() {
  buttonHandler.poll();
  timerDisplay.setArmed(buttonHandler.isArmed());

  if (buttonHandler.stopResetPressed()) {
    if (wsClient) {
      wsClient->emitTimerControl("stop");
      wsClient->emitTimerControl("reset");
    }
    timerDisplay.setChordConfirmed();
  }

  if (buttonHandler.startStopPressed()) {
    if (wsClient) {
      if (timerDisplay.getTimer().isRunning()) {
        wsClient->emitTimerControl("stop");
      } else {
        wsClient->emitTimerControl("start");
      }
    }
  }

  timerDisplay.update();
  Ethernet.maintain();
  WebServer::handleClient(timerDisplay);
  if (wsClient) {
    wsClient->poll();
  }
}

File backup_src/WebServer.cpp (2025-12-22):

#include "WebServer.h"
#include "RGBMatrix.h"
#include "WebSocketClient.h"
#include <EthernetBonjour.h>
#include <SPI.h>

// Debug flag - set to false to disable debug messages for better timing
#define DEBUG_WEBSERVER false

// Debug printing macros
#if DEBUG_WEBSERVER
#define DEBUG_PRINT(x) Serial.print(x)
#define DEBUG_PRINTLN(x) Serial.println(x)
#else
#define DEBUG_PRINT(x)
#define DEBUG_PRINTLN(x)
#endif

// Font includes (12pt and below for 64x32 display)
#include <Fonts/FreeMono12pt7b.h>
#include <Fonts/FreeMono9pt7b.h>
#include <Fonts/FreeMonoBold12pt7b.h>
#include <Fonts/FreeMonoBold9pt7b.h>
#include <Fonts/FreeSans12pt7b.h>
#include <Fonts/FreeSans9pt7b.h>
#include <Fonts/FreeSansBold12pt7b.h>
#include <Fonts/FreeSansBold9pt7b.h>
#include <Fonts/FreeSerif12pt7b.h>
#include <Fonts/FreeSerif9pt7b.h>
#include <Fonts/FreeSerifBold12pt7b.h>
#include <Fonts/FreeSerifBold9pt7b.h>
// Retro/pixel fonts
#include <Fonts/Org_01.h>
#include <Fonts/Picopixel.h>
#include <Fonts/TomThumb.h>
// Custom fonts
#include <CustomFonts/AquireBold_8Ma6012pt7b.h>
#include <CustomFonts/AquireLight_YzE0o12pt7b.h>
#include <CustomFonts/Aquire_BW0ox12pt7b.h>

namespace WebServer {
// Pin definitions for Silicognition PoE-FeatherWing on RP2040-Shim
const int CS = 24;   // D24 (User confirmed CS rewired to D24/Pin36)
const int SCK = 10;  // Shim SPI SCK (GP10)
const int MOSI = 11; // Shim SPI MOSI (GP11)
const int MISO = 12; // Shim SPI MISO (GP12)

EthernetServer *server = nullptr;
bool mdns_initialized = false;
WebSocketClient *wsClient = nullptr;
int current_orientation = 180; // Track current display orientation

bool init(uint8_t mac[6], uint8_t ip[4]) {
  // Configure SPI pins for W5500
  SPI.setSCK(SCK);
  SPI.setTX(MOSI);
  SPI.setRX(MISO);
  SPI.setCS(CS);

  // Must call SPI.begin() to actually start the SPI peripheral
  SPI.begin();

  // Tell Ethernet library which CS pin to use
  Ethernet.init(CS);

  // Try DHCP first, fall back to static IP if DHCP fails
  DEBUG_PRINTLN("Attempting DHCP...");
  if (Ethernet.begin(mac, 30) == 0) {
    DEBUG_PRINTLN("DHCP failed, using static IP");
    // DHCP failed, use static IP
    Ethernet.begin(mac, IPAddress(ip[0], ip[1], ip[2], ip[3]));
  } else {
    DEBUG_PRINTLN("DHCP successful");
  }

  // Give Ethernet time to initialize and establish link
  delay(2000);

  // Check if Ethernet is connected
  if (Ethernet.hardwareStatus() == EthernetNoHardware) {
    DEBUG_PRINTLN("ERROR: Ethernet hardware not found");
    return false;
  }

  if (Ethernet.linkStatus() == LinkOFF) {
    DEBUG_PRINTLN("WARNING: Ethernet cable not connected");
  }

  DEBUG_PRINT("Ethernet initialized - IP: ");
  DEBUG_PRINTLN(Ethernet.localIP());

  return true;
}

bool initMDNS(const char *hostname) {
  if (!EthernetBonjour.begin(hostname)) {
    DEBUG_PRINTLN("ERROR: Failed to start mDNS responder");
    mdns_initialized = false;
    return false;
  }

  DEBUG_PRINT("mDNS responder started: ");
  DEBUG_PRINT(hostname);
  DEBUG_PRINTLN(".local");
  mdns_initialized = true;
  return true;
}

void updateMDNS() {
  if (mdns_initialized) {
    EthernetBonjour.run();
  }
}

String getIPAddressString() {
  IPAddress ip = Ethernet.localIP();
  return String(ip[0]) + "." + String(ip[1]) + "." + String(ip[2]) + "." +
         String(ip[3]);
}

void startWebServer(uint16_t port) {
  if (server != nullptr) {
    delete server;
  }
  server = new EthernetServer(port);
  server->begin();
  DEBUG_PRINT("Web server started on port ");
  DEBUG_PRINTLN(port);
}

EthernetServer &getServer() { return *server; }

void setWebSocketClient(WebSocketClient *client) {
  wsClient = client;
  DEBUG_PRINTLN("WebSocket client registered with WebServer");
}

// Helper function to send HTTP response
void sendHTTPResponse(EthernetClient &client, int code, const char *contentType,
                      const String &body) {
  client.print("HTTP/1.1 ");
  client.print(code);
  client.println(code == 200 ? " OK" : " Error");
  client.print("Content-Type: ");
  client.println(contentType);
  client.println("Connection: close");
  client.println();
  client.print(body);
}

// Helper function to URL decode a string
String urlDecode(const String &str) {
  String decoded = "";
  char temp[] = "00";
  for (unsigned int i = 0; i < str.length(); i++) {
    char c = str.charAt(i);
    if (c == '%' && i + 2 < str.length()) {
      temp[0] = str.charAt(i + 1);
      temp[1] = str.charAt(i + 2);
      decoded += (char)strtol(temp, NULL, 16);
      i += 2;
    } else if (c == '+') {
      decoded += ' ';
    } else {
      decoded += c;
    }
  }
  return decoded;
}

// Helper function to parse hex color string to RGB
void parseColor(const String &hexColor, uint8_t &r, uint8_t &g, uint8_t &b) {
  String color = hexColor;
  if (color.startsWith("#")) {
    color = color.substring(1);
  }

  long number = strtol(color.c_str(), NULL, 16);
  r = (number >> 16) & 0xFF;
  g = (number >> 8) & 0xFF;
  b = number & 0xFF;
}

// Helper function to get font pointer from font ID
const GFXfont *getFontById(int fontId) {
  switch (fontId) {
  case 0:
    return nullptr; // Default font (5x7 pixels)
  // Sans-Serif fonts
  case 1:
    return &FreeSans9pt7b;
  case 2:
    return &FreeSans12pt7b;
  case 3:
    return &FreeSansBold9pt7b;
  case 4:
    return &FreeSansBold12pt7b;
  // Monospace fonts
  case 5:
    return &FreeMono9pt7b;
  case 6:
    return &FreeMono12pt7b;
  case 7:
    return &FreeMonoBold9pt7b;
  case 8:
    return &FreeMonoBold12pt7b;
  // Serif fonts
  case 9:
    return &FreeSerif9pt7b;
  case 10:
    return &FreeSerif12pt7b;
  case 11:
    return &FreeSerifBold9pt7b;
  case 12:
    return &FreeSerifBold12pt7b;
  // Retro/Pixel fonts
  case 13:
    return &Org_01;
  case 14:
    return &Picopixel;
  case 15:
    return &TomThumb;
  // Custom fonts
  case 16:
    return &Aquire_BW0ox12pt7b;
  case 17:
    return &AquireBold_8Ma6012pt7b;
  case 18:
    return &AquireLight_YzE0o12pt7b;
  default:
    return &FreeSansBold12pt7b; // Default to 12pt bold
  }
}

// Helper function to get text size for font ID
uint8_t getTextSizeForFont(int fontId) {
  // Default font and retro fonts use larger scaling
  if (fontId == 0)
    return 2; // Default 5x7 @ 2x
  if (fontId >= 13 && fontId <= 15)
    return 3; // Retro fonts @ 3x (they're very small)
  return 1;   // All other fonts @ 1x
}
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

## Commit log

2025-10-05 added docs, Waveshare demos, and pins header file
    [active3-rpi-hub75-adapter.kicad_pcb, active3-rpi-hub75-adapter.sch, passive-rpi-hub75-adapter.kicad_pcb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]
2025-10-08 First light! Working LED matrix demo
2025-10-10 First working draft of RGB Matrix timer with web UI
    [active3-rpi-hub75-adapter.kicad_pcb, active3-rpi-hub75-adapter.sch, passive-rpi-hub75-adapter.kicad_pcb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]
2025-10-10 WIP: add custom fonts (currently missing characters)
    [main.cpp]
2025-10-10 feat: websocket connection to browser-based timers
2025-10-10 feat: direct socket.io websocket connection between hardware timer and FightTimer (less lag than bridge setups)
2025-10-18 Rename Comms files to WebServer, add DHCP support, and clean up implementation as much as possible
    [active3-rpi-hub75-adapter.kicad_pcb, active3-rpi-hub75-adapter.sch, passive-rpi-hub75-adapter.kicad_pcb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]
2025-12-22 feat: Update RGB matrix pin definitions for RP2040-Shim, add a minimal test function, reorder WebServer includes, and remove a custom font.
2025-12-23 fix: Correct matrix pinout in docs and code, update SPI CS, and add raw GPIO toggle for wiring diagnosis.
    [RGBMatrix.cpp, main.cpp]
2025-12-25 feat: Integrate Adafruit_Protomatter library, relocate original source files to backup, and add new development utilities and documentation.
    [serial_dump.txt]
2025-12-26 feat: Implement WebServer and TimerDisplay features, and add EthernetBonjour and WebSockets library dependencies.
2025-12-27 feat: Implement persistent storage for timer display settings including duration, color thresholds, font, and letter spacing.
2025-12-30 feat: Add physical buttons for Start, Stop/Reset, and Network Info, including their handling logic and wiring documentation.
    [main.cpp]
2026-01-17 feat: Add initial KiCad schematic and symbols for the RP2040 Arena Timer with HUB75 matrix, and update firmware and documentation.
    [arena_timer.kicad_sch]
2026-05-31 fix: resolve HUB75 panel startup crash, UART conflict, and signal integrity timing
    [serial_dump.txt]
2026-05-31 feat(01-01): add ButtonHandler class header (D-01, D-04, D-05, D-06)
    - #pragma once guard (not #ifndef per project convention)
    - Declares constructor ButtonHandler(uint8_t pin1, uint8_t pin2)
    - Declares begin() for hardware init in setup()
    - Declares poll() for non-blocking update in loop()
    - Private members: _pin1, _pin2, _b1, _b2 (leading underscore + snake_case)
    - No event accessors — Phase 1 scaffold only
2026-05-31 feat(01-01): implement ButtonHandler class (D-05, D-06, BTN-01, BTN-02)
    - Constructor stores pin1/pin2 only via member initializer list, no hardware work
    - begin() calls attach(pin, INPUT_PULLUP) + interval(25) for both buttons (BTN-01)
    - poll() calls _b1.update() + _b2.update() non-blocking (BTN-02)
    - DEBUG_BUTTONHANDLER=true enables serial diagnostic output for Phase 1 verification
    - No delay(), no separate pinMode(), no update() called more than once per instance
2026-05-31 docs(01-01): complete ButtonHandler foundation plan summary
    - SUMMARY.md for Phase 01 Plan 01 (BTN-01, BTN-02, BTN-03 satisfied)
    - 3 tasks committed: Bounce2 in platformio.ini, ButtonHandler.h, ButtonHandler.cpp
2026-05-31 feat(01-02): wire ButtonHandler into main.cpp (BTN-01, BTN-02)
    - Add #include "ButtonHandler.h" to project headers block
    - Add #define BTN_1 14 / BTN_2 15 to HARDWARE PIN CONFIGURATION block
    - Declare ButtonHandler buttonHandler(BTN_1, BTN_2) as file-scope global
    - Add buttonHandler.begin() in setup() as section 2 (renumber Ethernet/Network/WS/Settings to 3-6)
    - Place buttonHandler.poll() as first call in loop() before timerDisplay.update()
2026-05-31 docs(01-02): complete ButtonHandler main.cpp wiring plan
    - Summary for plan 01-02: ButtonHandler wired into main.cpp, pio run exits 0
2026-05-31 docs(02-button-ux): create phase 2 plans — ButtonHandler state machine + display overlay
2026-05-31 feat(02-01): implement ButtonHandler armed state machine (BTN-04, BTN-05, BTN-06)
    - Add isArmed(), startStopPressed(), stopResetPressed() public API to header
    - Add _armed, _startStopPending, _stopResetPending private members
    - Rewrite poll() with ordered state machine: reset flags, arm check, disarm on rose(), B1 routing
    - Extend constructor initializer list with _armed(false), _startStopPending(false), _stopResetPending(false)
    - Remove Phase 1 BTN1 fell / BTN2 fell diagnostics (D-12); replace with Phase 2 state messages
    [ButtonHandler.cpp]
2026-05-31 feat(02-01): add WebSocketClient emitTimerControl stub (D-05, D-07)
    - Declare emitTimerControl(const char* action) in WebSocketClient.h public section
    - Implement at end of WebSocketClient.cpp using strcmp dispatch pattern
    - Calls _timer->start() / _timer->stop() / _timer->reset() for Phase 2 local stub
    - Phase 3 seam: prepend Socket.IO emit before local calls without renaming
    [WebSocketClient.cpp]
2026-05-31 docs(02-01): complete ButtonHandler state machine + emitTimerControl plan
2026-05-31 feat(02-02): TimerDisplay armed overlay — setArmed() + update() short-circuit (D-09, D-10, D-11, BTN-07)
    - Added void setArmed(bool armed) public declaration to TimerDisplay.h with doxygen comment
    - Added bool _armed private member after _was_expired in TimerDisplay.h
    - Extended constructor init list with _armed(false) in TimerDisplay.cpp
    - Added setArmed() implementation with transition-aware blink state reset on both arm and disarm
    - Added armed short-circuit block at top of update(): 1Hz blink of warm yellow STOP? at x=17 y=12
    - Armed block uses _matrix.setFont(NULL) for predictable default font sizing
    - Armed block returns early, skipping all expired/paused/running logic below
2026-05-31 feat(02-02): main.cpp button event routing (D-06, D-08, BTN-04, BTN-05, BTN-06)
    - Added timerDisplay.setArmed(buttonHandler.isArmed()) immediately after buttonHandler.poll()
    - Added stopResetPressed() check before startStopPressed() (chord reset takes priority)
    - stopResetPressed branch calls emitTimerControl(stop) then emitTimerControl(reset) via wsClient null-guard
    - startStopPressed branch toggles: isRunning() -> emitTimerControl(stop), else -> emitTimerControl(start)
    - timerDisplay.update() moved after all button routing per D-11 anti-pattern
    - All emitTimerControl calls wrapped in if (wsClient) null-guard
    [main.cpp]
2026-05-31 docs(02-02): complete TimerDisplay armed overlay + main.cpp button event routing plan
2026-05-31 feat: show solid red RESET overlay after chord reset
    After B2+B1 chord reset, display shows solid red "RESET" until the
    timer is next started (B1 press). Armed overlay (STOP?) still takes
    priority while B2 is held.
    [main.cpp]
2026-05-31 feat: rework armed overlay to RESET? / RESET. UX
    B2 held → flashing yellow RESET? (was STOP?)
    B2+B1 chord → solid red RESET. (while B2 still held)
    B2 released → normal timer (now reset)
    [main.cpp]
2026-05-31 docs(03): create Phase 3 Socket.IO integration plan
    Single-wave plan covering SYNC-01 (emit-first timer_control), SYNC-02
    (500ms one-shot echo suppression), and SYNC-03 (request_timer_status
    time sync with heartbeat guard and initial-sync skip). Two tasks: header
    private member additions and five surgical WebSocketClient.cpp edits.
2026-05-31 feat(03-01): implement SYNC-01 + SYNC-02 + SYNC-03 in WebSocketClient.cpp
    - SYNC-01: emitTimerControl() sends 42["timer_control",{"action":"..."}] via
    sendTXT() before calling local timer method; offline actions skip emit
    - SYNC-02: 500ms one-shot echo suppression in handleTimerUpdate(); suppression
    window set only when connected; cleared on first matching action
    - SYNC-03: runtime start requests timer_status with {"timer_id":1}; timer_status
    branch in handleWebSocketEvent() applies time_left via setDuration+reset+start;
    is_initial_sync flag skips round-trip on connect sync; heartbeat guard prevents
    5s polling flood; _initialSyncPending cleared on disconnect
    [WebSocketClient.cpp]
2026-05-31 fix: correct namespace format from /timerN to /timer/N to match FightTimer multi-timer paths
    [WebServer.cpp]
2026-05-31 revert: restore /timerN namespace format — FightTimer uses /timer1 not /timer/1
    [WebServer.cpp]
2026-05-31 fix: sanitize stale EEPROM namespace on boot to stop /timer/1 bad connects
    EEPROM was left with '/timer/1' from a previously reverted bad-fix commit
    (f44c163). The current code generates valid '/timer1' options in the web UI
    dropdown, but loadSettings() accepted any non-empty string, so the stale
    value survived every reboot and caused every Socket.IO connect packet to
    send '40/timer/1,' which FightTimer rejects.
    On boot, validate the loaded namespace against the known-valid set ('/' and
    '/timer1'..'/timer5'). If invalid, reset to '/' and immediately overwrite
    the bad EEPROM bytes so the very next boot is also clean. The user then
    selects the correct timer from the web UI dropdown and Connec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
    [WebSocketClient.cpp]
2026-06-01 fix: namespace prefix on emits + font restore after armed overlay
    - Add /timer1 namespace prefix to timer_control and request_timer_status
    emits — without it FightTimer never received button actions
    - Restore _current_font/_text_size at top of draw() so the armed overlay
    cannot corrupt the display font state after chord reset
    [WebSocketClient.cpp]
2026-06-01 fix: remove request_timer_status round-trip; update v1.0 planning artifacts
    FightTimer truncates time_left to whole seconds, so the round-trip caused
    a 1s offset on fresh starts (arena showed 2:59 while FightTimer showed 3:00).
    Both timers now start from configured duration simultaneously — no sync needed.
    Also closes out all GSD planning artifacts for v1.0: ROADMAP, REQUIREMENTS,
    and STATE updated to reflect all 3 phases UAT-complete.
    [WebSocketClient.cpp]
2026-06-07 docs: add updated integration guide with physical button control and bidirectional Socket.IO
    Updates following recent pushes — adds sections on timer_control events emitted
    by physical buttons, timer_status sync event, is_heartbeat/is_initial_sync flags,
    echo suppression behavior, and correct FightTimer namespace format.
2026-06-07 docs: add integration changelog — delta from original guide to current firmware
2026-06-07 fix: add 999ms duration offset for correct first-second display; add V2 hardware files
    Timer.cpp: setDuration adds 999ms so the first displayed second is fully
    visible under floor-rounding. TimerDisplay.cpp: minor refactor of
    getDisplayTime remaining time return.
    [ScoreboardPCB-Mini.kicad_pcb, ScoreboardPCB-Mini.step, ScoreboardPCB-MoreMiniMini.kicad_pcb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]
